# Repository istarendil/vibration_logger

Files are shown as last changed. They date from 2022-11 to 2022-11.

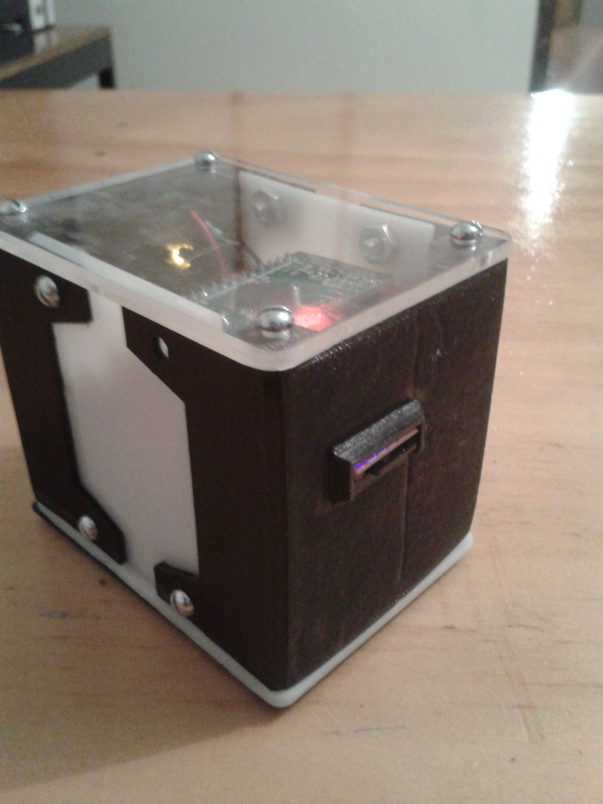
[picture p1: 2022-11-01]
doc/img/2016-10-13 19.51.44.jpg

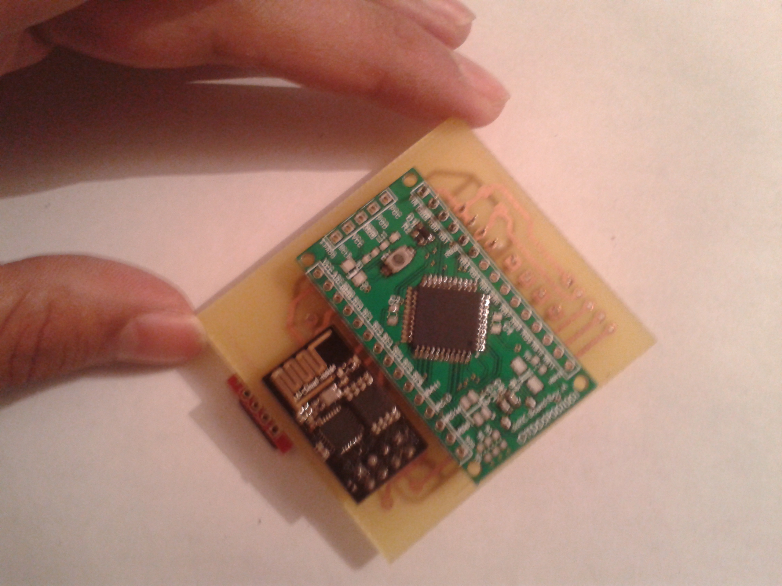
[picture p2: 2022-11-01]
doc/img/2016-09-04 22.14.03.jpg

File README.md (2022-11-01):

# vibration_logger
The main idea of this project is to build a device capable of measuring vibrations in structures such as buildings and transmitting the information obtained to a database that can be accessed remotely through the internet. The objective of having a remote monitoring system is to collect useful data on the state of the buildings for its later analysis.

logger
pcb1

This project was commissioned by the Department of Structural Analysis of the Faculty of Engineering of the Autonomous University of the State of Mexico to the System Dynamics and Control Laboratory. 

pcb2
pcb3

# Tools and materials
- esp8266
- dsPic30f3014
- RTC DS1302

# Software
|name| version|
|----|---|
|MPLAB X| 10 |
|C16 compiler|1.25|
|Matlab| 2016|

# Directories and files
- The firmware/logger directory contains the source code written for the C16 compiler in MPLAB X.
- The firmware/esp8266 folder contains the different versions of the esp8266 firmware.
- The firmware/configuration_files folder contains the necessary files for the operation of the logger and for the connection to the Wi-fi network, as well as a file that shows how the data is stored.
- The pcb folder contains the PCB design files.
- The Excel document at te test folder contains a test performed on the prototype, where data was acquired and the results were graphed.

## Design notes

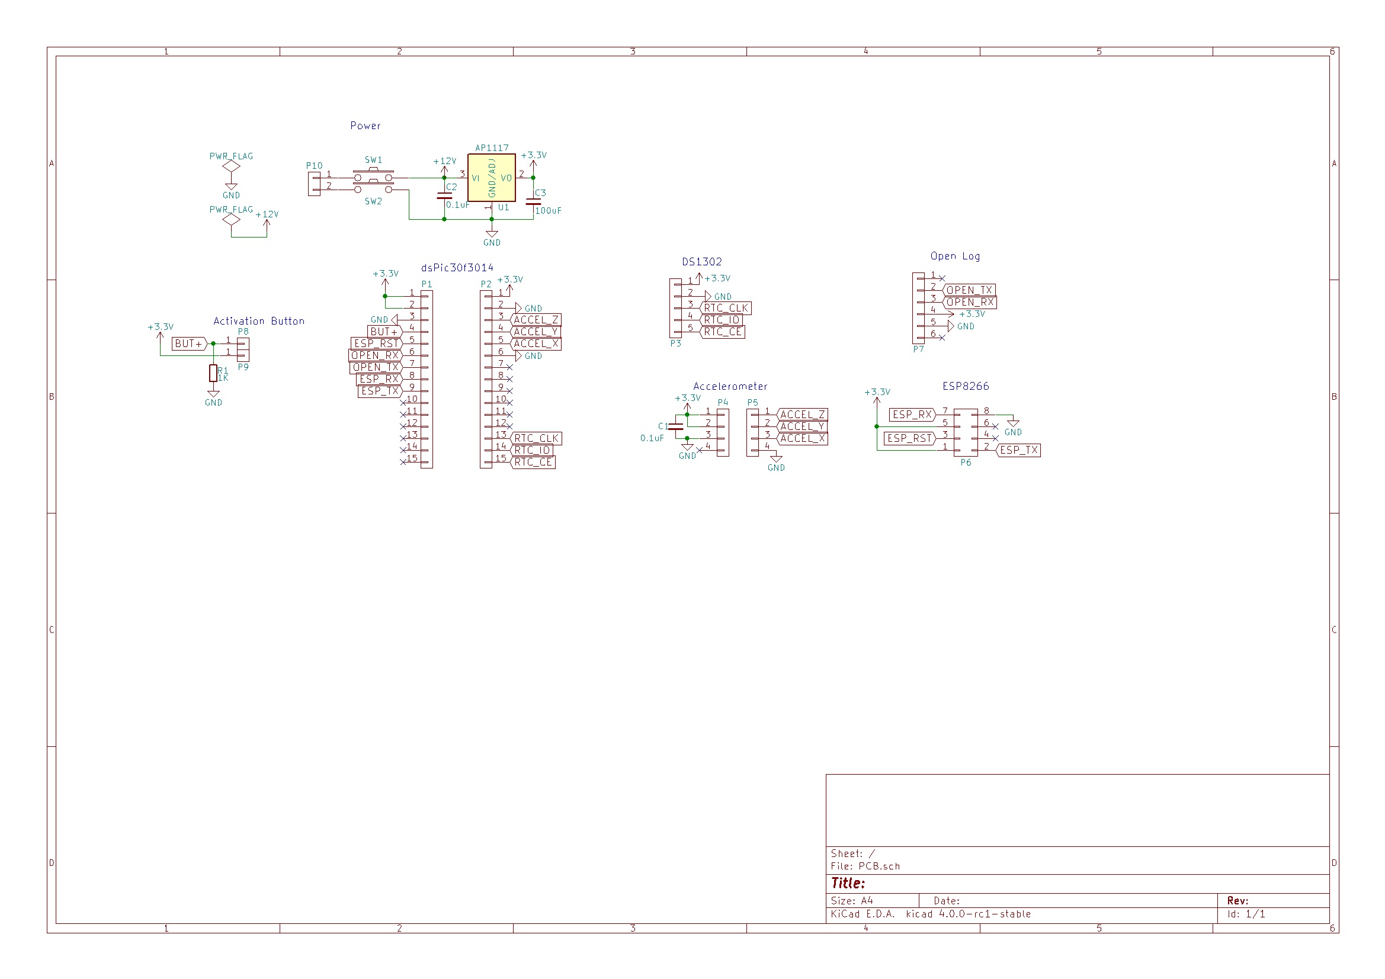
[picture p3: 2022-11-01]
doc/img/Schematic.jpg

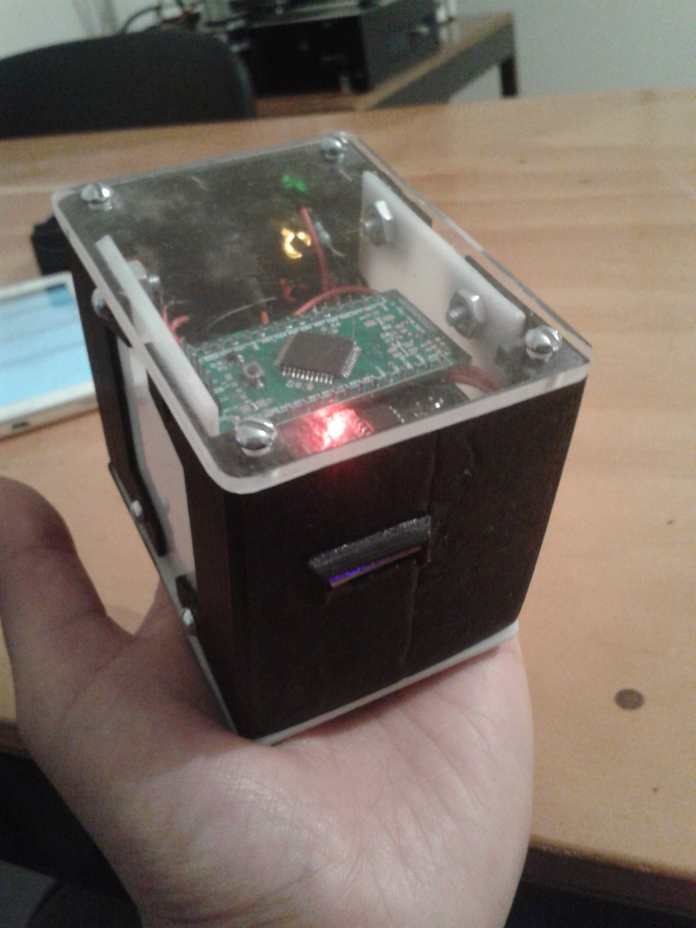
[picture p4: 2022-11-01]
doc/img/2016-10-13 19.52.28.jpg

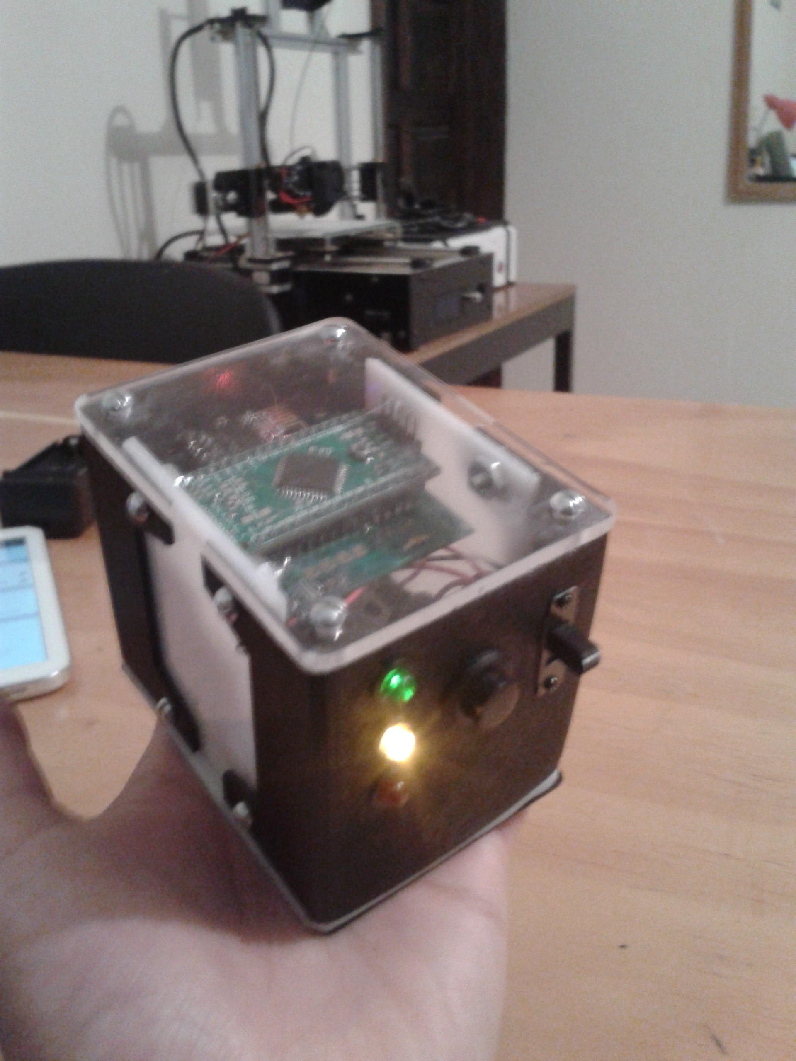
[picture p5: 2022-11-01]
doc/img/2016-10-13 19.52.05.jpg

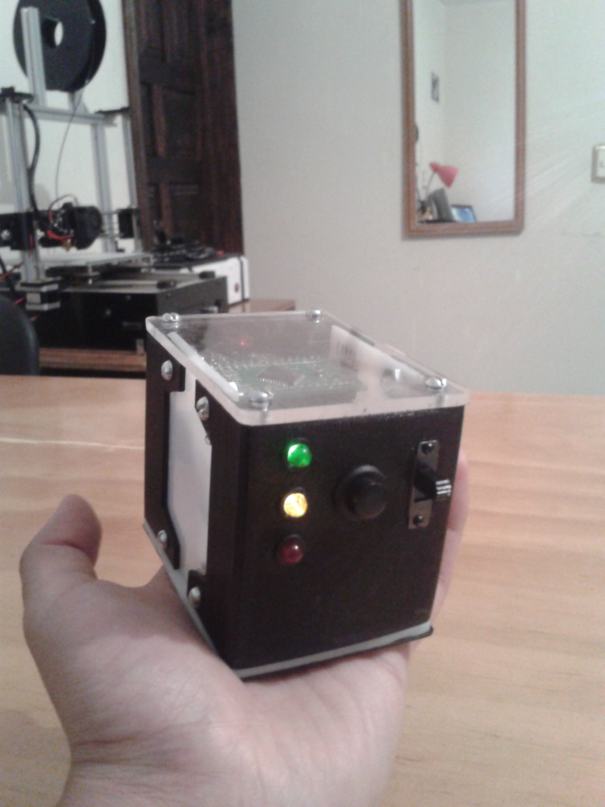
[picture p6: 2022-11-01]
doc/img/2016-10-13 19.56.36.jpg

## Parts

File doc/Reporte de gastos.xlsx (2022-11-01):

Elemento | Cantidad | Provedor | Costo unitario | Costo total
Tarjetas con dsPic | 2 | A-Electronics | $165 | $330
Tarjetas sin dsPic | 1 | A-Electronics | $50 | $50
Baterias Li-Po 3.7v | 2 | A-Electronics | $75 | $150
Cargadores Li-Po 1s | 2 | A-Electronics | $80 | $160
Pilas Li-ion 3.7v | 2 | Electrocomponentes | $90 | $180
Módulos RTC | 2 | A-Electronics | $60 | $120
Cargador de pilas Li-ion | 1 | Mercadolibre | $189+95(envio) | $284
Portapilas doble | 1 | A-Electronics | $35 | $35
Portapilas sencillo | 3 | A-Electronics | $30 | $90
Pilas de boton | 2 | GOMI | $16 | $32
Conectores, botones, resistencias, capacitores, cables, materiales | NA | NA | NA | $214
Inversion total |  |  |  | $1645
Presupuesto original |  |  |  | $2500
Presupuesto restante |  |  |  | $855

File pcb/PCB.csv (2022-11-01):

 |  | ADC-BATT1 | ADC-EXT2 | ADC-EXT3 | ADC-EXT4 | ADC-EXT5 | LED-BATT1 | LED-OK1
Id | Designator | Package | Quantity | Designation | Supplier and ref
1 | C1 | C_1206_HandSoldering | 1 | 100nF
2 | P1P2 | Socket_Strip_Straight_1x15 | 2 | CONN_01X15
3 | P3 | Socket_Strip_Straight_1x05 | 1 | CONN_01X05
4 | P4P5 | Socket_Strip_Straight_1x04 | 2 | CONN_01X04
5 | P7 | Socket_Strip_Straight_1x06 | 1 | CONN_01X06
6 | P8P9
7 | P10LED-ON1" | Socket_Strip_Straight_1x01 | 10 | CONN_01X01
8 | SW1SW2 | Socket_Strip_Straight_1x02 | 2 | SW_PUSH
9 | P6 | Socket_Strip_Straight_2x04 | 1 | CONN_02X04
10 | U1 | sot223 | 1 | AP1117
11 | C2 | c_tant_A | 1 | 1uF
12 | C3 | c_tant_C | 1 | 100uF
13 | R1 | R_0805_HandSoldering | 1 | 1K
14 | R2 | R_0805_HandSoldering | 1 | 12K
15 | R3 | R_0805_HandSoldering | 1 | 22K

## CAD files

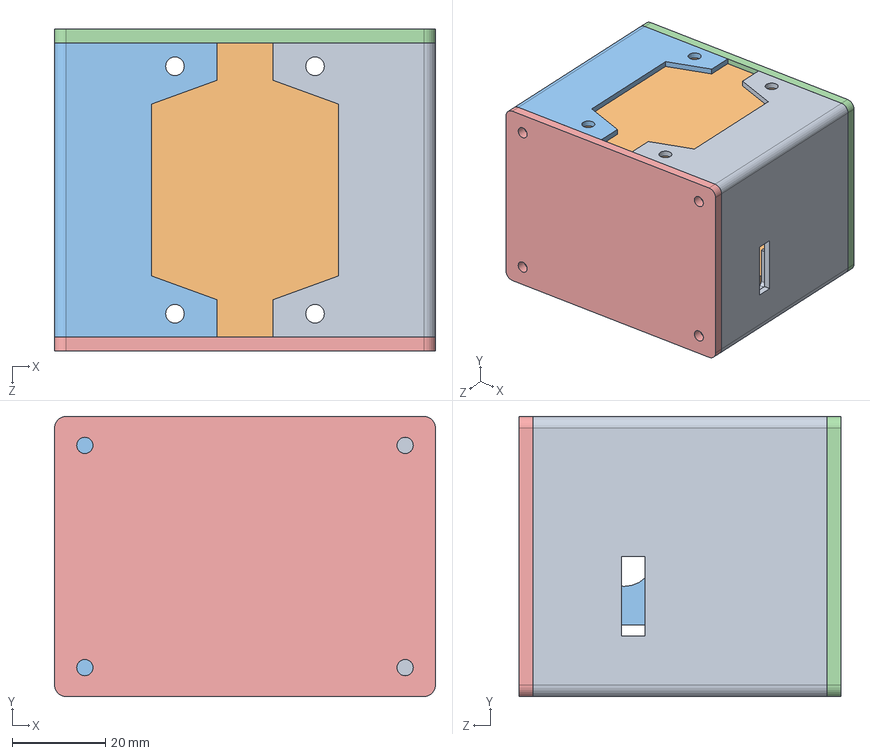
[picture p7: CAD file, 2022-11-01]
cad/case/caja V1.SLDASM
81.6 x 60.0 x 69.0 mm
Tapa frontal
Tapa lateral x 2
Tapa trasera
Tapa superior

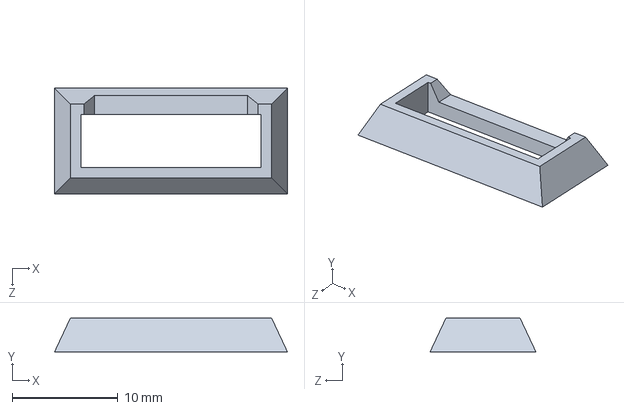
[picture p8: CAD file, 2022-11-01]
cad/case/SD-Card.SLDPRT
22.0 x 3.20 x 10.0 mm

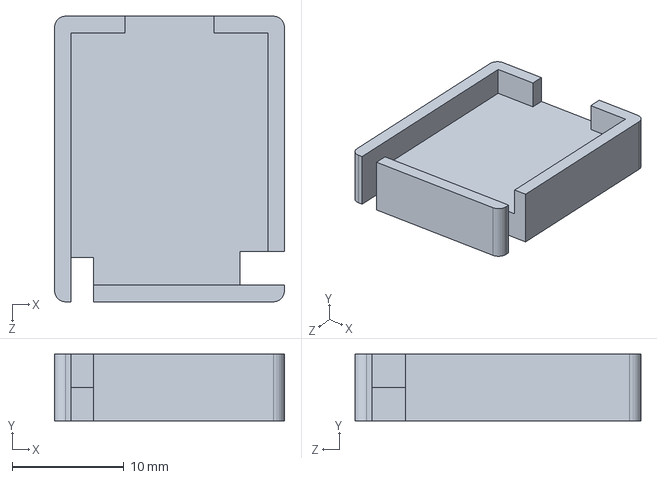
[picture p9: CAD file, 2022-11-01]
cad/charger/Cargador.SLDPRT
20.6 x 6.00 x 25.6 mm

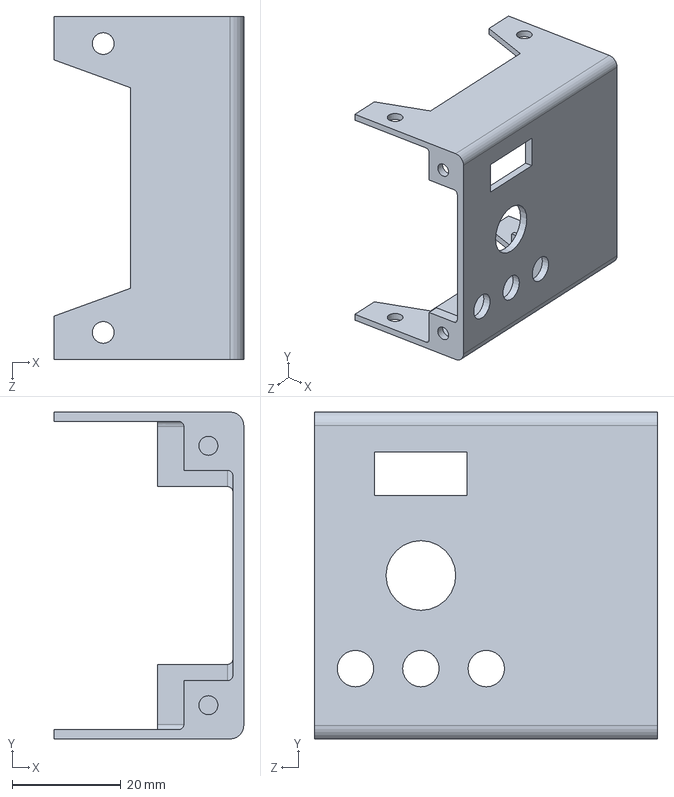
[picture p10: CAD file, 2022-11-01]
cad/case/Tapa trasera.SLDPRT
34.8 x 60.0 x 63.0 mm

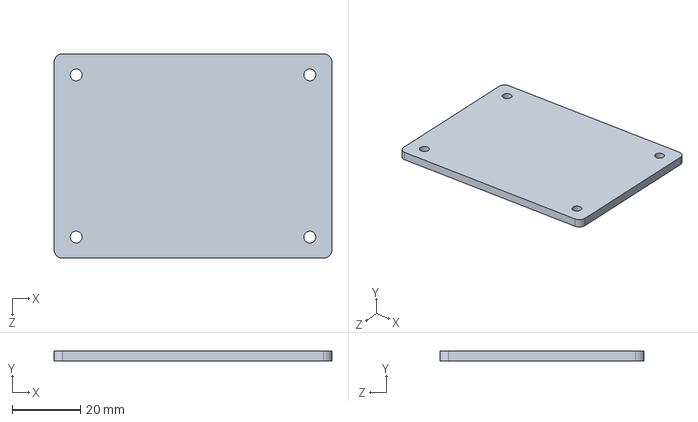
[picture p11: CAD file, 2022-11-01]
cad/case/Tapa superior.SLDPRT
81.6 x 3.00 x 60.0 mm

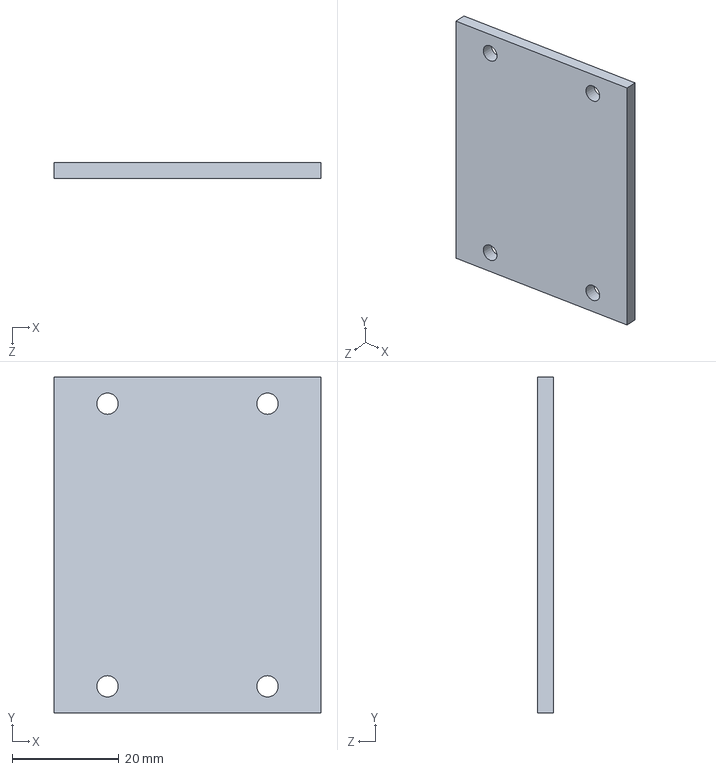
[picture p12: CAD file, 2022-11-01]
cad/case/Tapa lateral.SLDPRT
50.0 x 63.0 x 3.00 mm

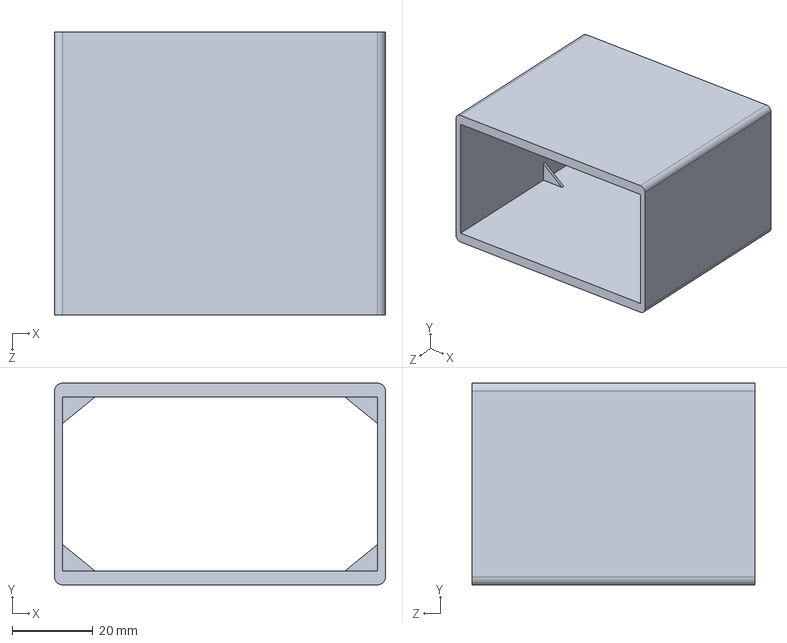
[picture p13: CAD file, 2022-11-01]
cad/case/Pieza1.STEP
82.0 x 50.0 x 70.0 mm

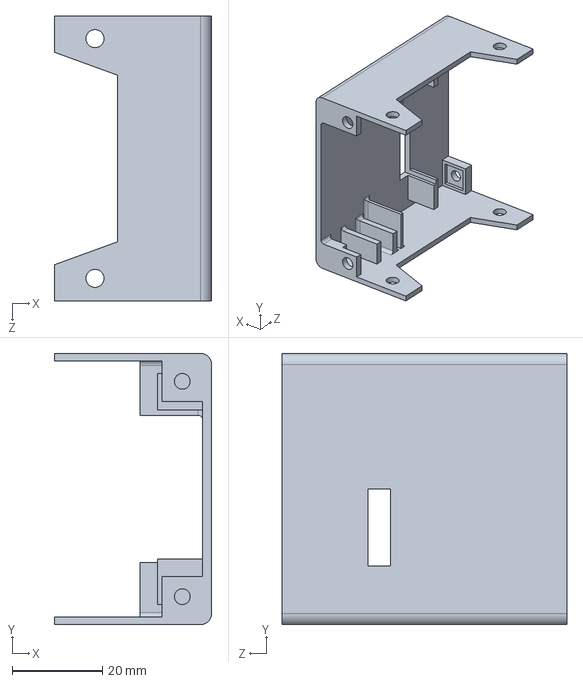
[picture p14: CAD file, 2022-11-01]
cad/case/Tapa frontal.SLDPRT
34.8 x 60.0 x 63.0 mm

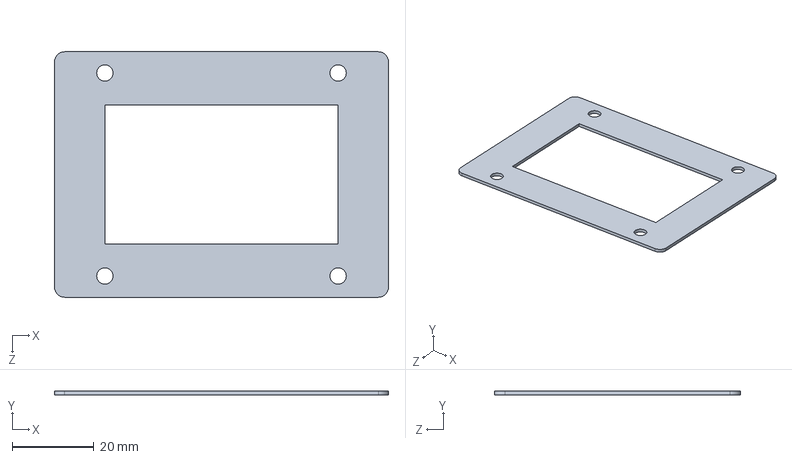
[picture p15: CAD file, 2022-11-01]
cad/case/Tapa inferior.SLDPRT
81.6 x 1.00 x 60.0 mm

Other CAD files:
cad/case/SD-Card.STL
cad/case/Tapa frontal.STL
cad/case/Tapa inferior.SLDDRW
cad/case/Tapa inferior.STL
cad/case/Tapa lateral.SLDDRW
cad/case/Tapa superior.SLDDRW
cad/case/Tapa trasera.STL
cad/charger/Cargador.STL

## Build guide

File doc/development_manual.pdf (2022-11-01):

# Registrador de vibraciones v1.0

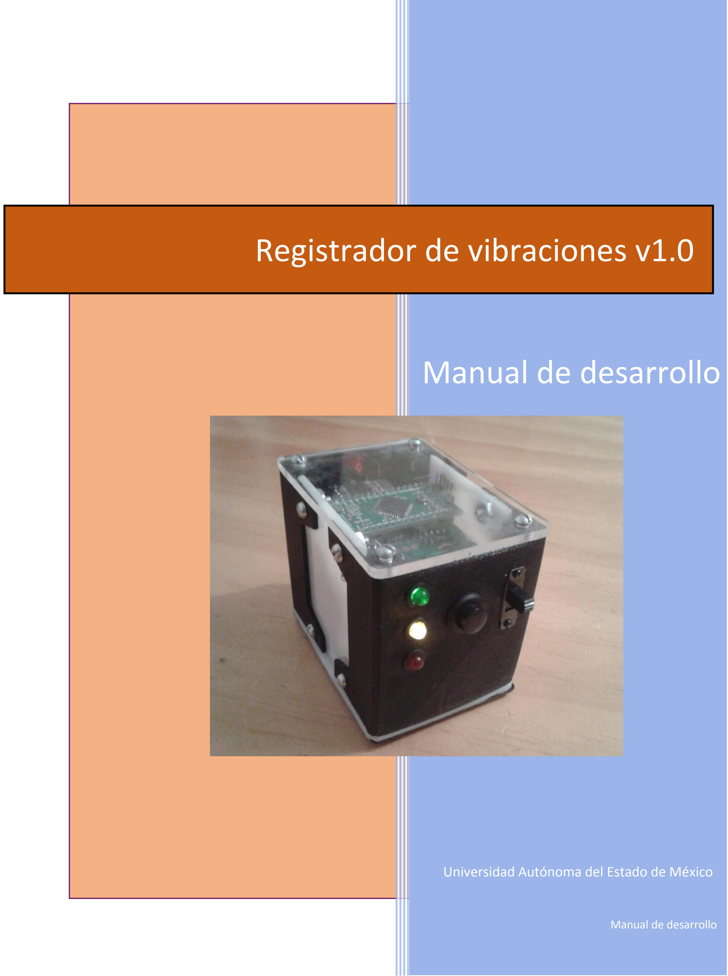
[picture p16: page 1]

# Manual de desarrollo

Universidad Autónoma del Estado de México

Manual de desarrollo

### Registrador de vibraciones v1.0

## Contenido

### 1. Programación del módulo Wi-Fi

El módulo ESP8266 es el elemento encargado de dar conectividad web al dispositivo. Originalmente viene precargado con un firmware que lo hace funcionar mediante comandos AT lo cual resulta conveniente si se desea configurara manualmente, pero dificulta su uso si se desea conectarlo a un microcontrolador.

Para facilitar el desarrollo de este proyecto el firmware del módulo ESP fue reescrito empleando el IDE de Arduino, esto permitió conectarlo a los servidores de la empresa Adafruit para crear un dispositivo de internet de las cosas capaz de ser activado en forma remota a través de una interfaz web.

1.1Requerimientos previos
Materiales empleados
- Esp8266-01
- Interfaz USB-serial FTDI232
- Arduino IDE 1.6.9

Instalación del Plug-in ESP8266 en el Arduino IDE

Instalar este plug-in en el IDE de Arduino permitirá programar el módulo wi-fi como una tarjeta arduino. A continuación se muestran los pasos para lograr esta tarea.

a) Abrir el IDE de arduino e ir a Archivo/Preferencias. En el recuadro de Gestor de URL´s adicionales de Tarjetas escribir la siguiente liga:

http://arduino.esp8266.com/package_esp8266com_index.json

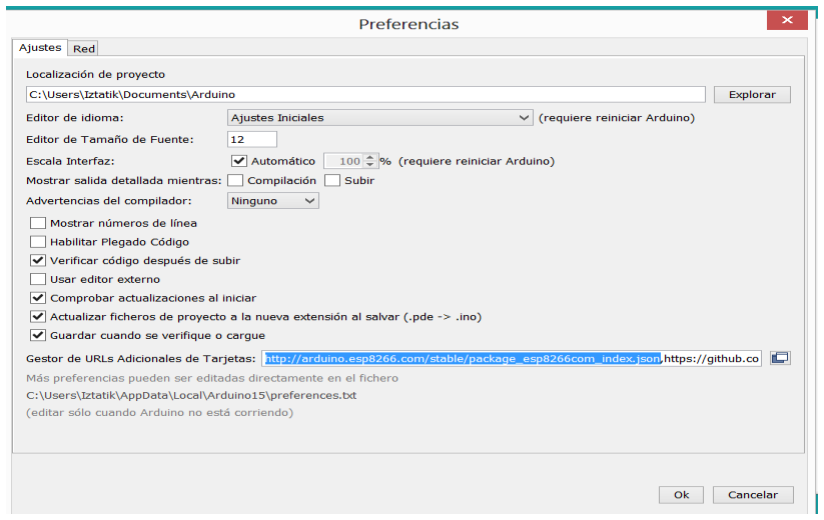
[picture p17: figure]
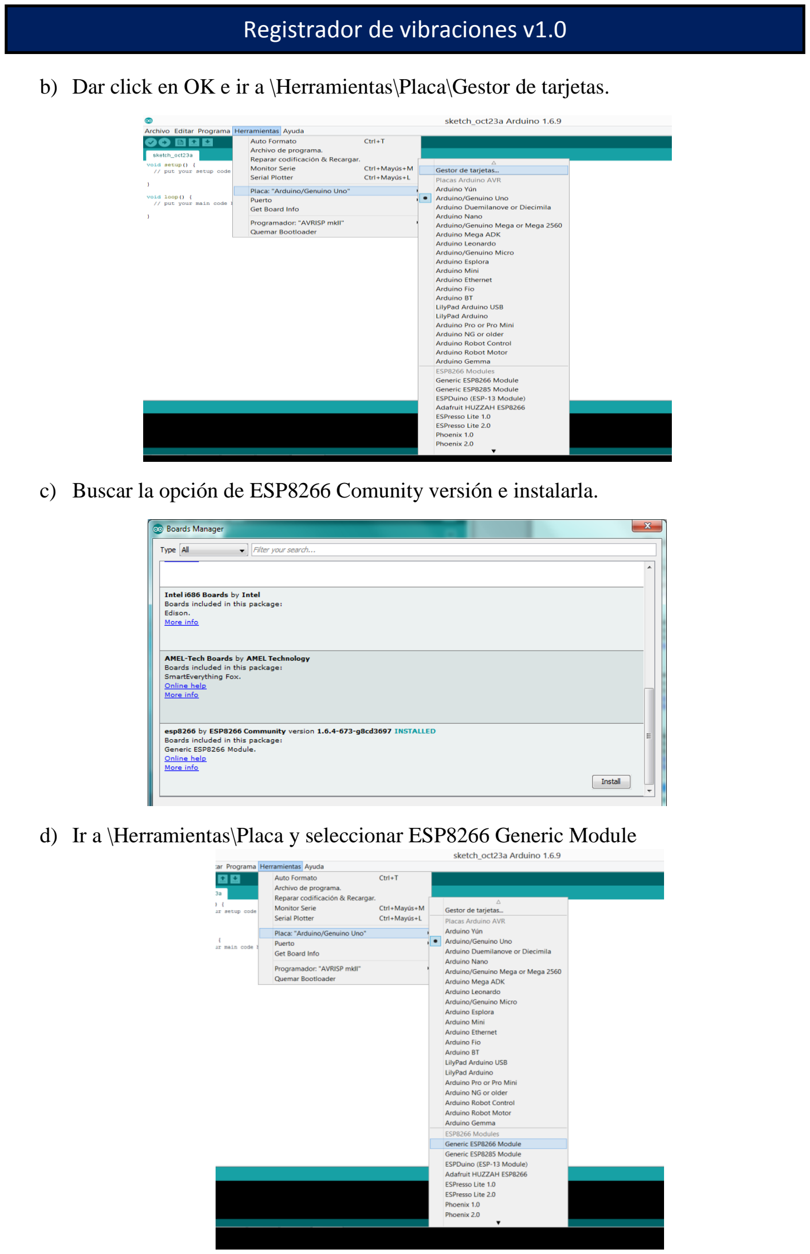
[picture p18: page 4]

b) Dar click en OK e ir a \Herramientas\Placa\Gestor de tarjetas.
c) Buscar la opción de ESP8266 Comunity versión e instalarla.
d) Ir a \Herramientas\Placa y seleccionar ESP8266 Generic Module e) Conectar la interfaz FTDI al módulo Wi-fi de la siguiente manera:

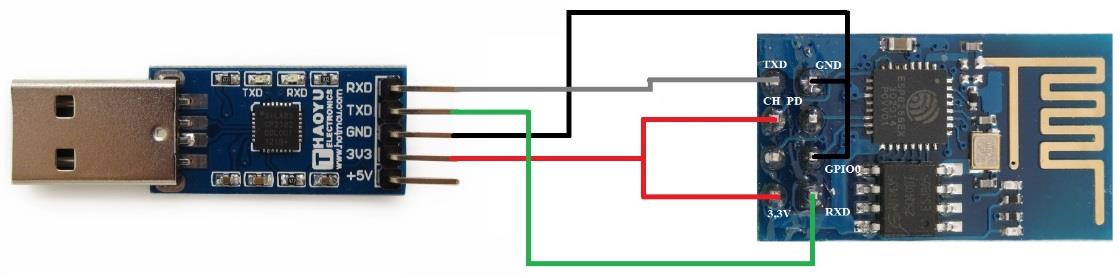
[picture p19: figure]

Instalación de la librería MQTT de Adafruit en el Arduino IDE

Esta librería permite la conexión del módulo Wi-fi a los servidores de la empresa Adafruit.

1) Diríjase al menú de Programa/Incluir Librería/ Gestor de Librerias

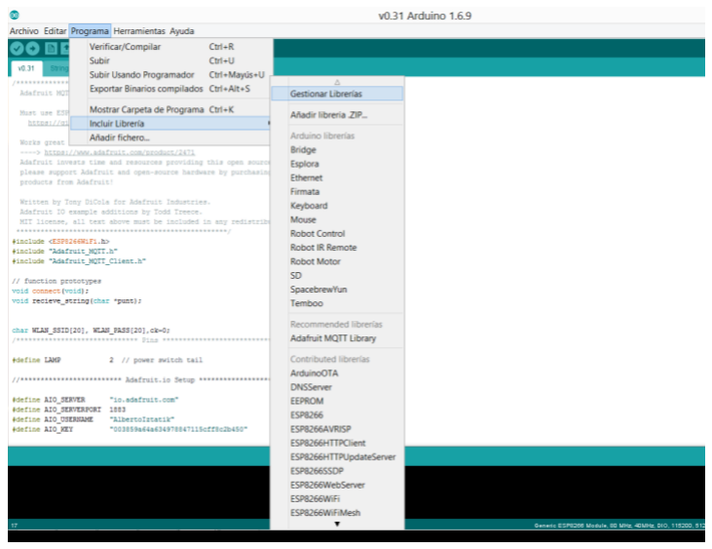
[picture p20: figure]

2) En el filtro de búsqueda escriba Adafruit. Busque, seleccione y de click en instalar a la opción de Adafruit MQTT Library.

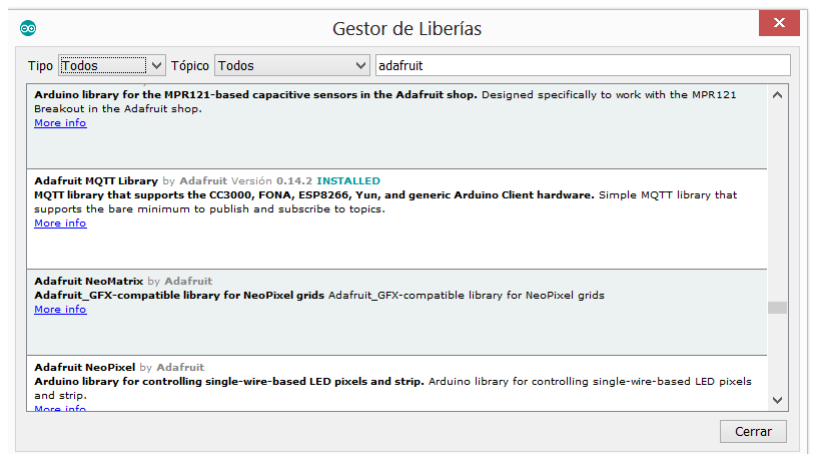
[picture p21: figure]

### 1.2 Creación de la interfaz web

Para la creación de la interfaz web es necesario tener un perfil o crear uno en la página oficial de Adafruit: https://accounts.adafruit.com/users/sign_in

Una vez creada la cuenta deben seguirse los siguientes pasos:

1) Ingresar a la página https://io.adafruit.com/ e iniciar sesión. Ir a la sección MyFeeds y crear un Feed con el nombre “lamp”. Se ha escogido este nombre con la finalidad de coincidir con el nombre planteado en el ejemplo base y la programación explicada en la sección 1.3.

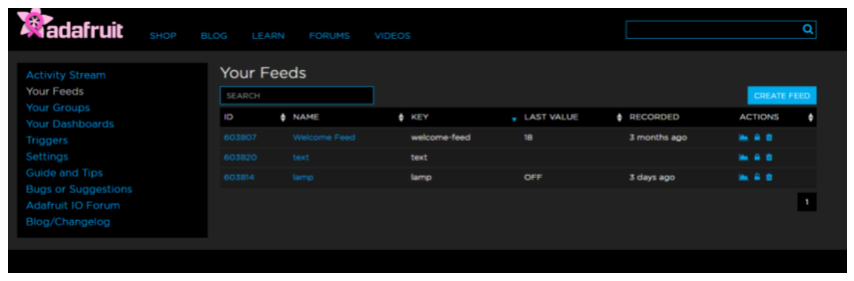
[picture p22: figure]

2) Ir a la sección My dashboarads y seleccionar Create Dashboard.

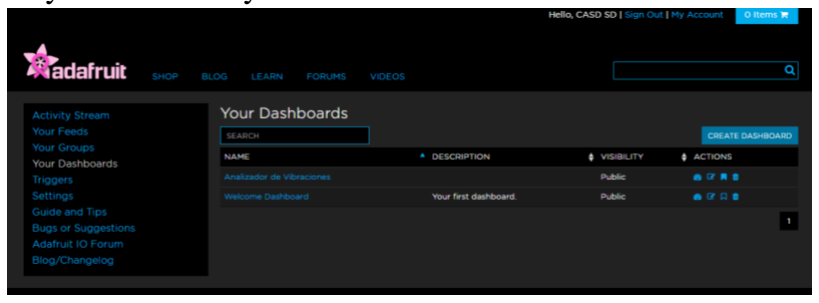
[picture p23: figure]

3) Seleccionar las opciones edit dashboard y créate block. Crear un elemento tipo botón y un elemento tipo cuadro de texto, ambos bajo el Group/Feed de “lamp”. Debe cuidarse que el campo de button on text sea llenado con la palabra “ON” y el button off text sea llenado con la palabra “OFF”

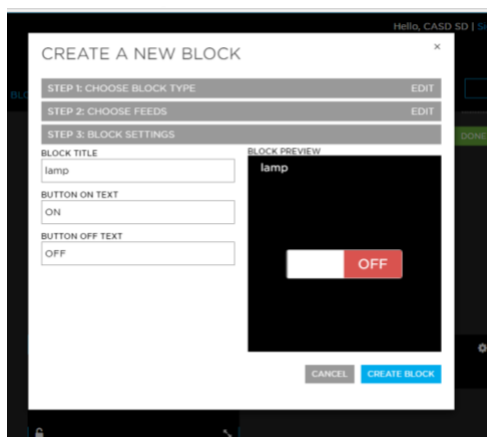
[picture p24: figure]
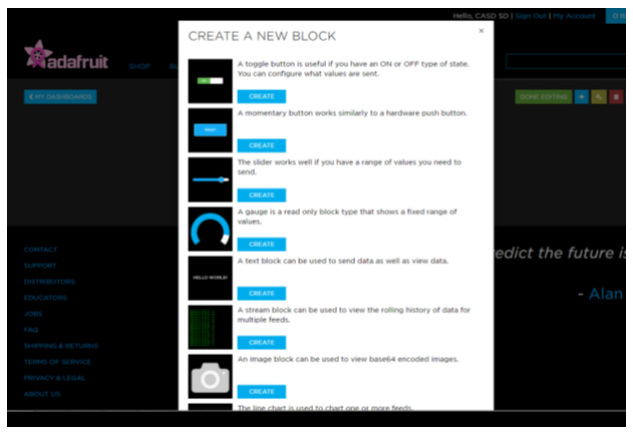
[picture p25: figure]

4) El resultado será una interfaz como la que se muestra a continuación:

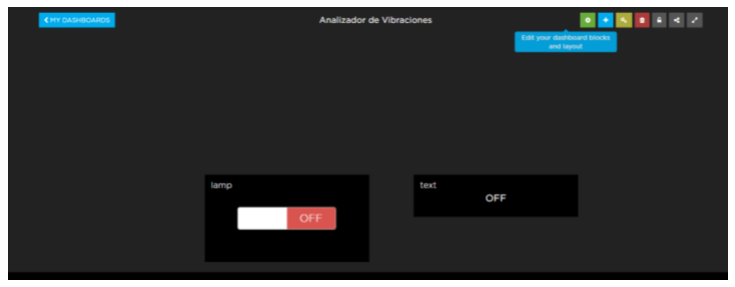
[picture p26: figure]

Para mayor información seguir la documentación disponible en la siguiente liga: https://learn.adafruit.com/adafruit-io-basics-feeds/overview

1.3Programación del módulo

Para la programación del módulo se tomó como base la idea fundamental del envío de una señal para el inicio o término de la grabación de datos del dispositivo. Para ello se partió de un ejemplo de código de la empresa Adafruit, el cual enciende y apaga una lámpara de forma remota a través de una interfaz web. El ejemplo puede ser descargado de la siguiente liga:

https://github.com/adafruit/adafruit-io-basics/tree/master/esp8266/digital_out

Teniendo este ejemplo como base se hicieron las siguientes modificaciones:

1) El ejemplo original contempla que se programe el nombre y clave de la red wlan de forma anticipada, no obstante esto se traduce en la necesidad de reprogramar el módulo cada vez que se quiera cambiar de red. Para evitar esto, se declararon estos valores como variables las cuales son definidas mediante una lectura serial cada vez que se enciende el módulo.

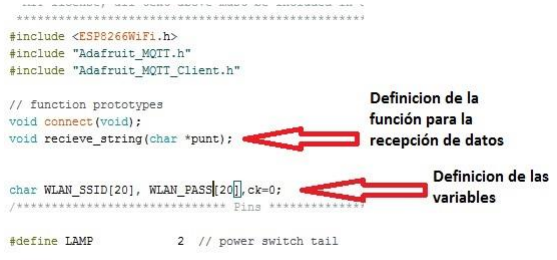
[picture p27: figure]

2) Se creó una función encargada de recibir los datos de las variables WLAN_SSID y WLAN_PASS cada vez que se enciende el módulo. Debe notarse que el código fuente de esta función se encuentra en una pestaña aparte de la función principal.

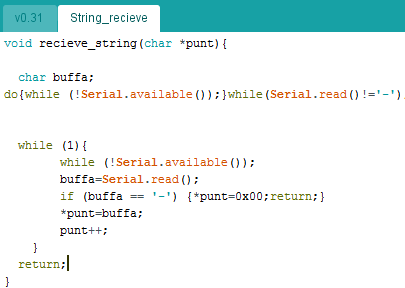
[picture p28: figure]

3) En la sección de definiciones se introdujeron el nombre de usuario y las claves AIO generadas al crear la interfaz web.

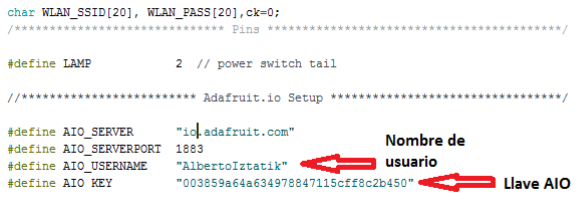
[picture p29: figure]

4) La función void setup fue modificada para iniciar la conexión wifi hasta asegurar la recepción vía serial y la definición de las variables del nombre y clave de la red wlan. También se modificó la velocidad de transmisión serial a 57600 baudios. En la función Serial.begin.

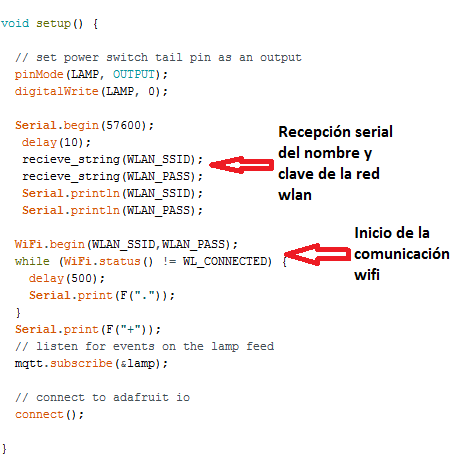
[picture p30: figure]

5) Se modificó la función void loop ara que al recibir la señal de encendido “ON” de la interfaz web, el módulo ESP envié de forma serial la letra “s” indicando el inicio de una nueva grabación de datos. De igual manera, al recibir una señal “OFF” el módulo ESP enviará de forma serial la letra “e” indicando la finalización de la grabación de datos. El DSC conectado al módulo ESP recibirá estos datos por su puerto serial y ejecutará las operaciones mencionadas.

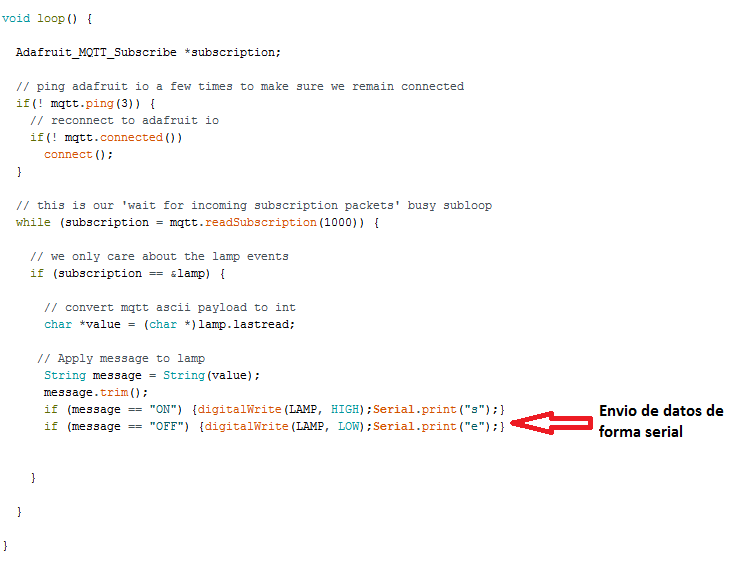
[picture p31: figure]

6) A lo largo de todo el código se eliminaron las impresiones seriales por el puerto serie que estaban definidas a excepción de las que muestra que el estado de conexión esta en proceso (.) y la que muestra una conexión exitosa (+).

Para mayor información seguir la documentación disponible en la siguiente liga: https://learn.adafruit.com/home-automation-in-the-cloud-with-the-esp8266-and-adafruit-io/introduction (https://learn.adafruit.com/home-automation-in-the-cloud-with-the-esp8266-and-adafruit-io/introduction)

### 2. Configuración del lector de tarjetas SD

EL lector de tarjetas SD Open Log se configura mediante tres archivos de texto. A

continuación se detalla la función de los mismos:

1) Archivo COUNT.- Lleva un conteo de los archivos de grabación generados,

permitiendo que el DSC conozca la cantidad de archivos generados hasta el momento

y pueda generar el archivo siguiente en la lista.

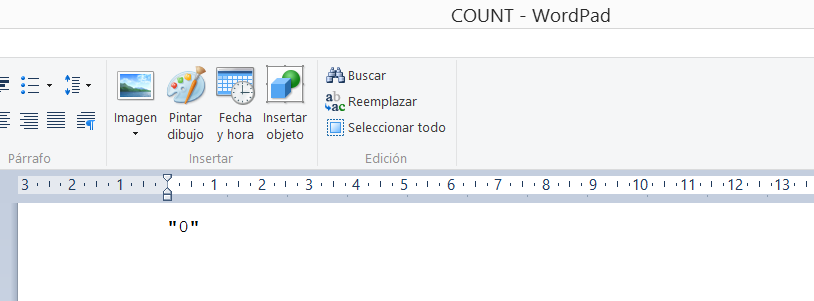
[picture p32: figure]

2) Archivo WLAN.- contiene los datos de la red de área local a la cual se conectará el

dispositivo, el DSC leerá este archivo para obtener esa información y posteriormente

enviarla al módulo ESP para que este realice la conexión.

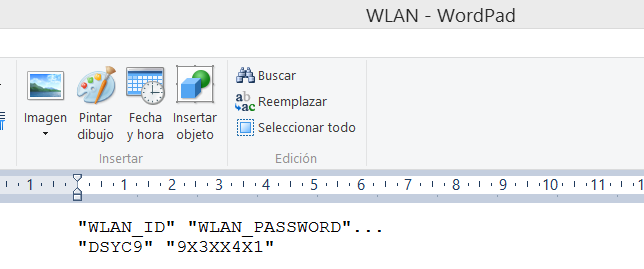
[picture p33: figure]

3) Archivo CONFIG.- Contiene los parámetros de configuración básica para la

comunicación serial de la tarjeta. Estos son en orden:

- Baudrate.- Velocidad de la conexión. 57600 para esta aplicación.
- Escape.- Valor en ASCII del carácter que permite poner al Open Log en modo

comando. Ctrl+z para esta aplicación.

- Esc#.- número de veces que debe leerse el carácter de escape para poner al Open

Log en modo comando. 3 para esta aplicación.

- Mode.- Modo con el que inicia el Open log al encenderse en cada ocasión. Modo

comando para esta aplicación (valor 0).

- Verb.- Responde con un carácter cada que se produce un error al leerse un

comando no reconocido. Apagado para esta aplicación (valor 0).

- Echo.- Responde con un carácter cada que se lee un dato por el puerto serial.

Apagado para esta aplicación (valor 0).

- Ignore RX.- Ignora la línea serial de RX por un periodo cada que se enciende el

Open Log. Apagado para esta aplicación (valor 0).

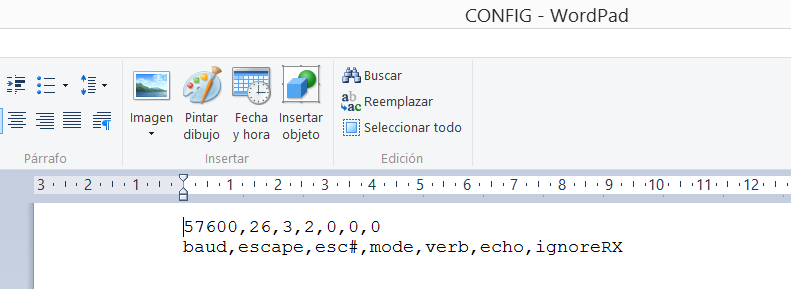
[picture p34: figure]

### 3. Programación del DSC

Herramientas empleadas:

- MPLABX IDE V3.10
- C16 Compliler V1.25
- Programador Pickit3
- dsPic30f3014

3.1Funciones del DSC

El DSC (controlador digital de señales) es el elemento de control principal del dispositivo. Como tal, es el encargado de interactuar con los otros elementos y gestionar sus tareas. A continuación se enumeran las funciones del DSC respecto a todos los elementos:

Lector de tarjetas SD Open Log:

- Creación y finalización de un nuevo archivo de grabación.- Al presionar el botón físico o virtual (interfaz web) el dispositivo leerá el contenido del fichero COUNT de la SD, incrementara en un valor este conteo, rescribirá dicho fichero con el valor incrementado y creará un nuevo fichero con el nombre del valor del conteo incrementado donde grabara los datos obtenidos del acelerómetro.
- Lectura del archivo de configuración de la red wlan.- Cada vez que se enciende el dispositivo, el DSC leerá vía serial los datos necesarios para la conexión a una red de área local del fichero WLAN en la tarjeta SD, posteriormente enviará estos datos al módulo wifi para que este pueda la conexión.

Módulo wifi ESP8266

- Envió de los datos de la red wlan.- El DSC lee estos datos del fichero WLAN de la tarjeta SD y posteriormente los envía vía serial al módulo ESP para que este entable la conexión.
- Recepción de los datos de activación.- Cada vez que se presiona el botón de la interfaz web, el DSC recibe vía serial las instrucciones para la creación o finalización de un archivo de grabación.

Reloj en tiempo Real

- Lectura del RTC.- El DSC lee el valor del reloj en tiempo real cada que se inicia o finaliza un archivo de grabación para escribir la hora en la que este fue iniciado y terminado.

Botón del dispositivo.- El DSC detectará que se ha presionado dicho botón e iniciará o detendrá la grabación de datos.

Gestión de energía de la batería.- El DSC determinará el nivel de carga de las pilas y encenderá el led rojo cuando estas estén totalmente descargadas.

3.2Mapa de conexión con otros elementos del dispositivo

El DSC y en general todos los elementos del dispositivo se encuentran conectados entre sí como muestra el siguiente diagrama esquemático:

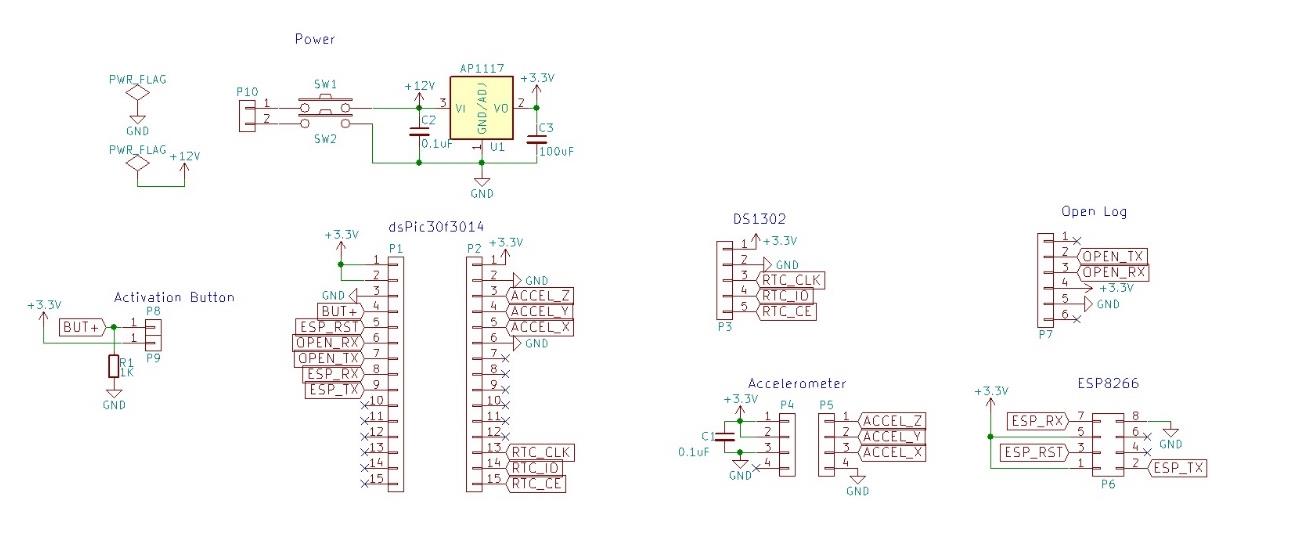
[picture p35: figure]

3.3Estructura del código fuente

El código fuente ha sido organizado en distintos ficheros para hacerlo lo más modular posible, dichos ficheros contienen un conjunto de funciones que al ser invocadas realizan funciones específicas del sistema. A continuación se detalla cada uno de estos ficheros y las funciones que contiene:

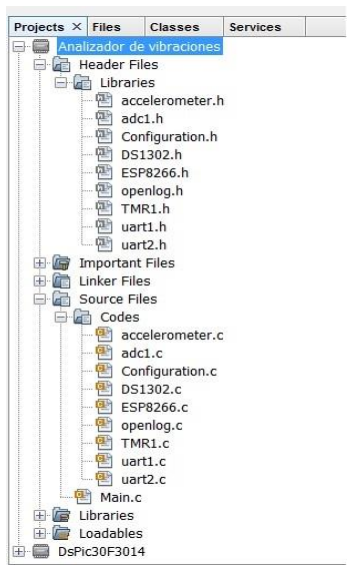
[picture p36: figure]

Archivos de cabecera:

a) accelerometer.h.- definición de variables y funciones del archivo acelerometer.c.
b) adc.h.- definición de variables y funciones del archivo adc.c.
c) Configuration.h.- definición de la frecuencia de reloj del sistema, inclusión de las librerías a emplear.
d) DS1302.h.- definición de variables y funciones del archivo DS1302.c
e) ESP8266.h.- definición de variables y funciones del archivo ESP8266.c.
f) openlog.h.- definición de variables y funciones del archivo openlog.c
g) TMR1.h.- Definición de la frecuencia de las interrupciones para las lecturas del ADC.
h) uart1.h.- Frecuencia y funciones para la comunicación serie con el Open Log
i) uart2.h.- Frecuencia y funciones para la comunicación serie con el ESP.

Archivos de código fuente:

a) accelerometer.c:
- ACCEL_get ().- Regresa la lectura de cualquier eje del acelerómetro convertida a un valor de voltaje.
b) adc.c:
- ADC1_initialize().- configura el ADC para su funcionamiento
- ADC1_getdata ().- realiza “manuelamente” el proceso de muestreo y conversión de un dato del ADC.
- BATT_get ().-Regresa la lectura del voltaje de la batería convertido a un valor de voltaje.
c) Configuration.c.- Contiene la definición de los fuses del DSC.
- SYSTEM_initialize ().- invoca todas las funciones de inicialización de cada función y gestiona el tiempo de retardo para que se ejecuten.
d) DS1302.h:
- DS1302_initialize ().- Inicializa el DS1302.
- DS1302_write ().- Hace una lectura en los registros del DS1302.
- DS1302_read ().- Realiza una lectura de los registros del DS1302.

- DS1302_bcd2bin ().- Convierte un dato de BCD a binario.
- DS1302_rgtclean ().- Determina el registro del RTC con el que se trabajará.
e) ESP8266.c:
- initilize_ESP8266 ().- Inicializa el ESP poniendo su pin de reset a 0.
- wlan_ESP8266 ().- Envía el ESP de forma serial los datos necesarios para la conexión a la red wlan.
f) openlog.c:
- OPENLOG_initilize ().- Lee los archivos WLAN y COUNT de la SD e invoca la función wlan_ESP8266 ().
- OPENLOG_get_string ().- Recibe una cadena de caracteres del puerto serial.
- OPENLOG_parser ().- Función que ejecuta un algoritmo de búsqueda en el string recibido para extraer la información útil.
- OPENLOG_completewrite ().- Escribe en una sola invocación las lecturas obtenidas del acelerómetro.
- OPENLOG_comandmode ().- Hace que el Open Log entre en modo comando.
- OPENLOG_newfile ().- crea un nuevo fichero de grabación en el Open Log.
- OPENLOG_printtime ().- Obtiene la hora del RTC y la imprime en un archivo en uso del Open Log.
g) TMR1.c:
- TMR1_initialize ().- Configura el timer 1 para realizar interrupciones cierto periodo.
h) uart1.c:
- UART1_initialize ().- Configura la comunicación serial.
- UART1_send_string ().- Envía una cadena de caracteres por el puerto.
i) uart2.c:
- UART2_initialize ().- Configura la comunicación serial.
- UART2_send_string ().- Envía una cadena de caracteres por el puerto.
- UART2_get_string ().- Recibe una cadena de caracteres por el puerto serial.
- _U2RXInterrupt ().- Rutina de interrupción que se genera al recibir un dato por el puerto.

Función principal main

La función main ejecuta el siguiente algoritmo:

1. Invoca la función SYSTEM_initialize () para inicializar todos los elementos.
2. Define las variables de la función.
3. Define el pin del botón como entrada y los pines de los leds como salidas.
4. Enciende el led verde indicando que el dispositivo está listo para iniciar una grabación, apaga el led rojo de la batería.
5. En el bucle infinito espera a que se produzca algún evento que inicie la grabación (presionar el botn o recepción serial).
6. Si se inicia la grabación se espera un tiempo para evitar rebotes del botón, se enciende el led amarillo y se genera un nuevo archivo.
7. Repetidamente se leen los datos de los ejes del acelerómetro y la batería, los primeros se imprimen en el archivo creado y el segundo se compara con un valor umbral que prende o apaga el led rojo.
8. Si se presiona de nuevo algún botón se apaga el led amarillo y se regresa al estado descrito en el inciso 5.

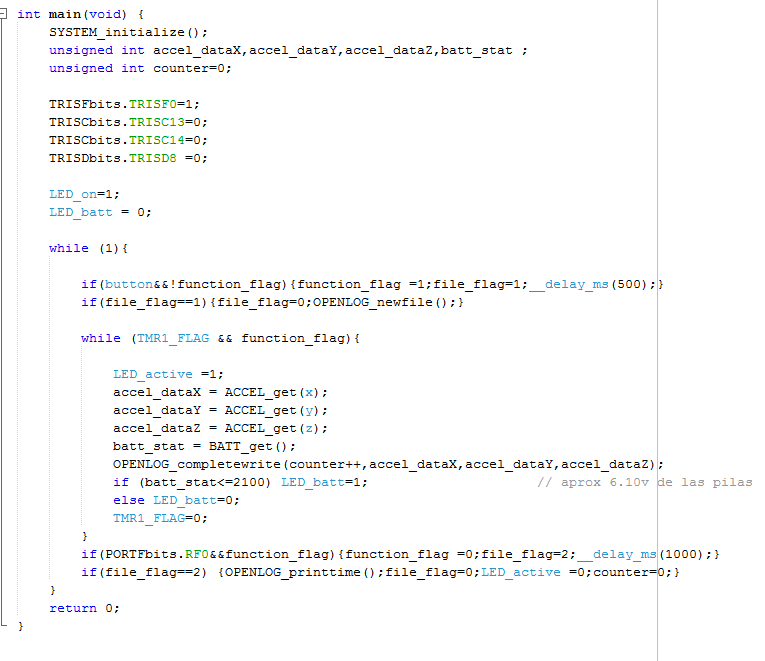
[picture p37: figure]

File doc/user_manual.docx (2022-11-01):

Manual de usuario

Universidad Autónoma del Estado de México

Manual de usuario

Registrador de vibraciones v1.0

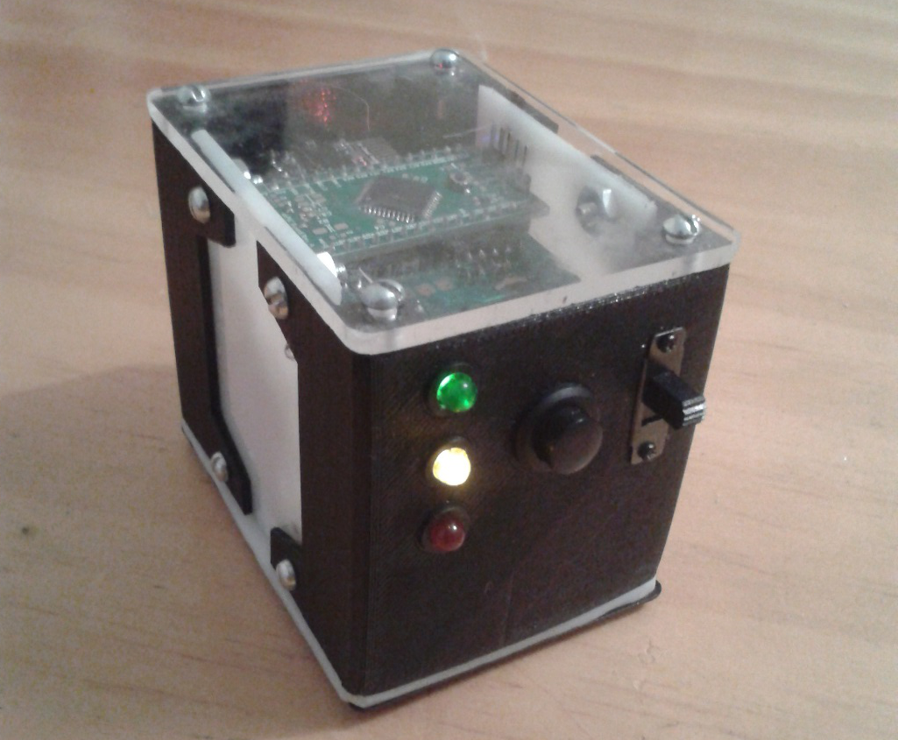
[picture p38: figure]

# 1. Partes del dispositivo

El dispositivo consta de las siguientes partes en la tapa frontal:

1. Interruptor de encendido y apagado.- Enciende el dispositivo al ponerse en una posición alta.
2. Botón de grabación de datos.- Al pulsarse inicia una nueva grabación de datos o detiene alguna en proceso.
3. Leds indicadores de estado
- Led verde.- Indica cuando el dispositivo está listo para comenzar la grabación de datos.
- Led amarillo.- Indica que la grabación de datos está en proceso.
- Led rojo.- Al encenderse totalmente (sin parpadeos), indica una carga baja de las pilas.

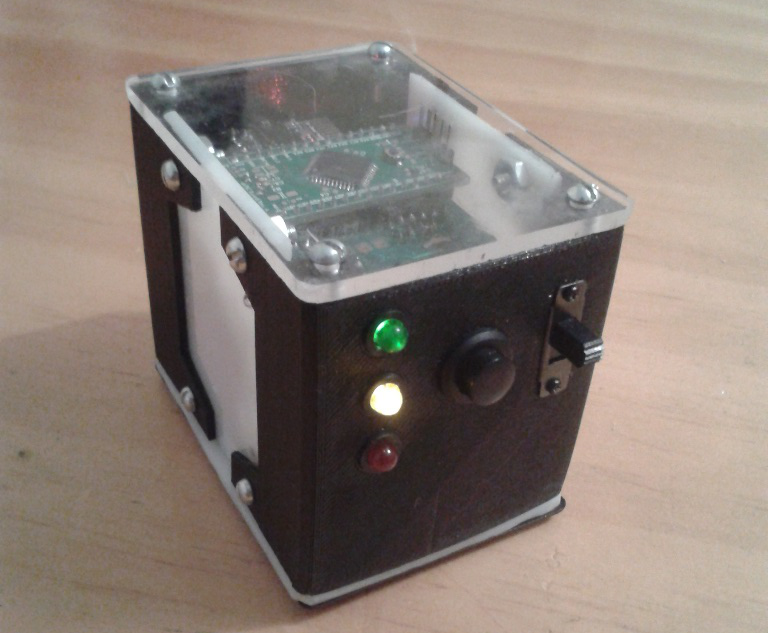
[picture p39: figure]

Figura 1: Vista frontal

El dispositivo consta de las siguientes partes en la tapa trasera:

1. Ranura de inserción para memoria micro SD.- Apartado donde se inserta la tarjeta SD.

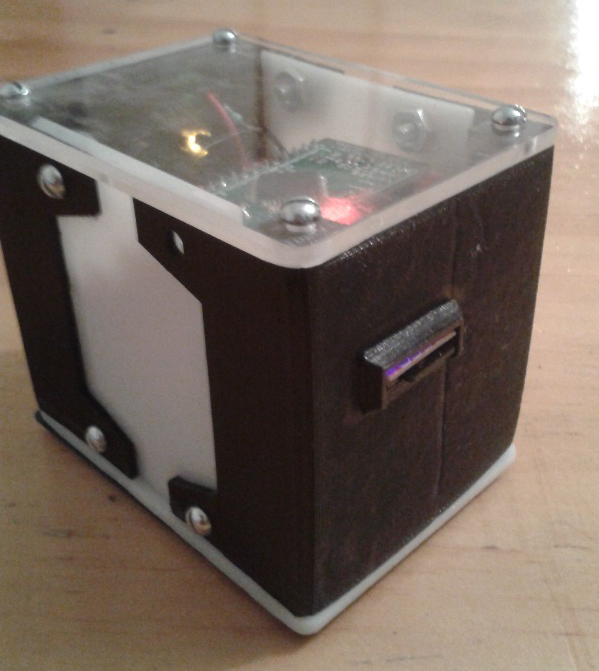
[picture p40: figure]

Figura 2: Vista trasera

# 2. Configuración y uso

A continuación se enumeran los pasos para utilizar el dispositivo:

1) Borre todos los documentos dentro de la tarjeta micro SD o de preferencia fórmatela a su valores de fábrica.
2) Copie los archivos CONFIG, COUNT y WLAN (carpeta Open_Log del CD) a la memoria micro SD.
3) Asegúrese que los archivos estén configurados de la siguiente manera:

El archivo COUNT lleva un conteo de los archivos de grabación generados, asegúrese que su valor inicial sea cero y este entrecomillado como muestra la siguiente imagen, de lo contrario se producirá un error.


Figura 3: Archivo COUNT

El archivo WLAN contiene los datos de la red de área local a la cual se conectará el dispositivo, introduzca estos datos de la forma en que los marcan los tirulos en el archivo, en el primer entrecomillado el nombre de la red y en el segundo entrecomillado la contraseña. De ninguna manera borre o altere los títulos en el primer renglón.


Figura 4: Archivo WLAN

El archivo CONFIG no debe ser modifica bajo ninguna circunstancia y debe asegurarse que coincida con los valores mostrados en la siguiente imagen.

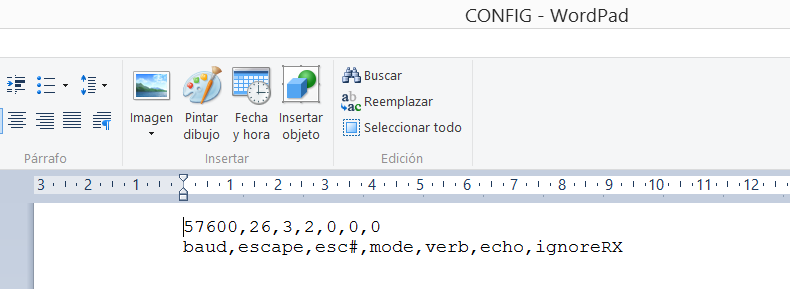
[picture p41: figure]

Figura 5: Archivo CONFIG

4) Inserte la tarjeta en la ranura y encienda el dispositivo accionando el interruptor en la tapa frontal
5) Observe la tapa superior (transparente) aproximadamente 5 segundos hasta que se produzca un destello azul proveniente del módulo wi-fi. Acto seguido, espere a que el led verde en la tapa frontal se encienda, esto indica que el dispositivo está listo para realizar una lectura.
6) Para realizar una lectura, presione y suelte rápidamente el botón ubicado en la tapa frontal. El led amarillo se encenderá indicando que la grabación de datos está en proceso. Repita este paso tantas veces como lecturas necesite.
7) Para retirar la tarjeta SD, siempre detenga cualquier grabación y apague con anterioridad el dispositivo. Retirar la tarjeta mientras se ejecuta un grabación o mientras el dispositivo está encendido puede corromper los datos de la misma, llevando a la necesidad de repetir los pasos 1 a 3.

No es necesario formatear la tarjeta y modificar los archivos de configuración cada ocasión que se use el dispositivo, para usos posteriores al primero simplemente trabaje desde el paso 4. Se recomienda revisar el estado de los archivos de configuración periódicamente para evitar fallos. Asegúrese de que los archivos no contengan espacios o saltos de línea al final de los datos requeridos.

Advertencia: Si después de usar el dispositivo se desea reiniciar el conteo de los archivos de grabación a un valor inicial, borre todos los archivos de grabación generados hasta el momento y regrese el valor del entrecomillado en el archivo COUNT a cero. Si se omite esta advertencia, los archivos con el mismo número de conteo comenzarán a sobrescribirse.

Control por internet del dispositivo

Para controlar remotamente el dispositivo ingrese al siguiente sitio:

https://io.adafruit.com/AlbertoIztatik/analizador-de-vibraciones

Se desplegara una página como muestra la siguiente imagen, si se desa puede ampliarse el área de control haciendo click en el icono de maximizar dentro de la interfaz:

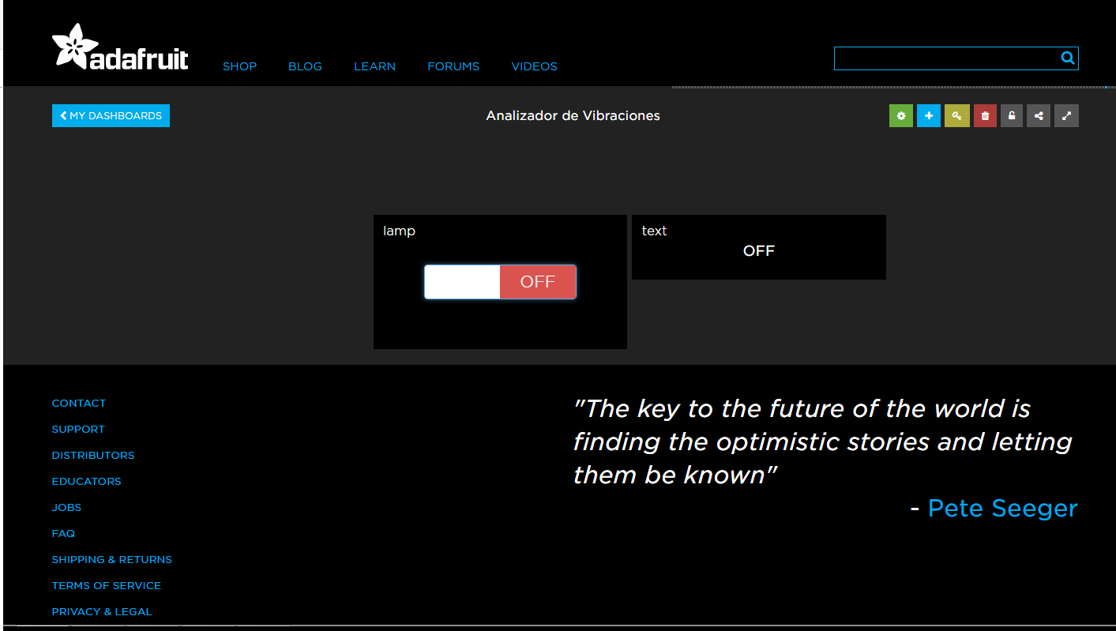
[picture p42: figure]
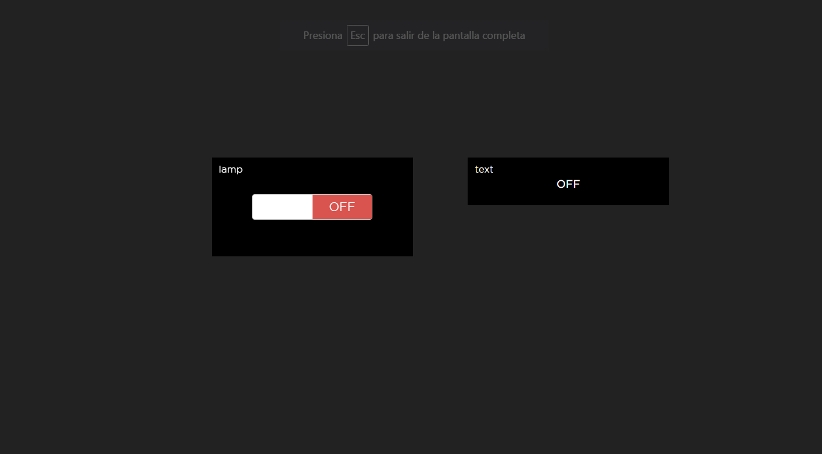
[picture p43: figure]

Figura 5: Interfaz web

Tanto el botón como el cuadro de texto de la interfaz realizan la misma función que el botón de grabación del dispositivo. Si se presiona el botón de la interfaz o se escribe la palabra ON en el cuadro de texto se iniciará una nueva grabación de datos en el dispositivo, volviendo a presionar el botón o escribiendo la palabra OFF y dando enter en el cuadro de texto se detiene la grabación.

La interfaz web proporcionada por la empresa Adafruit es un prototipo que se encuentra aún en fase de desarrollo, por lo que resulta habitual que el dispositivo no reciba la orden de iniciar o detener una grabación al primer intento. Se recomienda hacer un uso mayoritario del cuadro de texto para enviar órdenes y pulsar la tecla enter en repetidas ocasiones, dejando pausas de 1 segundo para asegurar el envío correcto de la orden.

# 3. Reprogramación y cambio de pilas

Para reprogramar el dispositivo siga los siguientes pasos:

1) Retire los tornillos de la tapa superior (transparente) con ayuda de un destornillador
2) Retire la tapa teniendo precaución de notar su alineación original
3) Coloque cables con headers tipo hembra en los headers tipo macho que sobresalen de la tarjeta del dsPic y conéctelos a su programador de preferencia. Tenga especial cuidado de no aplicar demasiada fuerza sobre los circuitos ya que podría romper con facilidad la estructura que los sostiene.
4) Encienda el dispositivo e inicie la reprogramación.
5) Coloque la tapa de la misma manera que esta se encontraba antes de ser retirada y sujétela con los tornillos.

Para cambiar las pilas del dispositivo siga los siguientes pasos:

1) Asegúrese que el led rojo ubicado en la tapa frontal se mantiene encendido sin parpadear al momento de hacer lecturas, esto indica que las pilas necesita una recarga.
2) Retire los tornillos de la tapa inferior con ayuda de un destornillador
3) Retire la tapa teniendo precaución de notar su alineación original
4) Extraiga con precaución el contenedor de pilas y retire las pilas del mismo. De ninguna manera fuerce los componentes ya que esto podría dañarlos. Si encuentra dificultad para extraer las pilas del contenedor, presione con algún elemento puntiagudo las baterías a través de los agujeros que se ubican en la parte trasera del contenedor teniendo cuidado de no dañar las mismas.
5) Coloque las pilas en el cargador e inicie el proceso de carga.
6) Una vez cargadas las pilas, colóquelas en el contenedor e introduzca este último en el dispositivo.

# 7) Coloque la tapa de la misma manera que esta se encontraba antes de ser retirada y sujétela con los tornillos.

Registrador de vibraciones v1.0

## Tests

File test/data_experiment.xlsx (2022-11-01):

Analizador de vibraciones FI-UAEMex
Martes: 16/8/16 23:17:39
EJEX | EJEY | EJEZ
1487 | 1492 | 2117
1509 | 1507 | 2122
1515 | 1507 | 2118
1514 | 1501 | 2123
1511 | 1514 | 2119
1513 | 1509 | 2122
1518 | 1507 | 2131
1511 | 1512 | 2115
1509 | 1508 | 2117
1512 | 1509 | 2123
1514 | 1507 | 2129
1507 | 1512 | 2112
1507 | 1508 | 2119
1511 | 1509 | 2120
1511 | 1501 | 2119
1511 | 1509 | 2118
1509 | 1505 | 2119
1513 | 1509 | 2122
1511 | 1505 | 2113
1514 | 1514 | 2116
1513 | 1507 | 2122
1514 | 1506 | 2132
1511 | 1507 | 2112
1511 | 1511 | 2118
1511 | 1507 | 2122
1513 | 1504 | 2128
1508 | 1513 | 2116
1508 | 1506 | 2122
1510 | 1505 | 2118
1511 | 1507 | 2121
1506 | 1511 | 2119
1511 | 1506 | 2123
1514 | 1505 | 2127
1509 | 1508 | 2112
1507 | 1507 | 2118
1512 | 1508 | 2121
1512 | 1504 | 2132
1510 | 1512 | 2111
1510 | 1508 | 2119
1514 | 1508 | 2121
1514 | 1504 | 2121
1514 | 1514 | 2118
1480 | 1508 | 2128
1514 | 1507 | 2121
1509 | 1505 | 2123
1507 | 1512 | 2119
1512 | 1508 | 2121
1516 | 1506 | 2131
1508 | 1507 | 2110
1507 | 1508 | 2115
1511 | 1509 | 2120
1516 | 1503 | 2132
1509 | 1514 | 2110
1510 | 1506 | 2120
1515 | 1505 | 2121
1513 | 1504 | 2124
1507 | 1514 | 2115
1509 | 1508 | 2121
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

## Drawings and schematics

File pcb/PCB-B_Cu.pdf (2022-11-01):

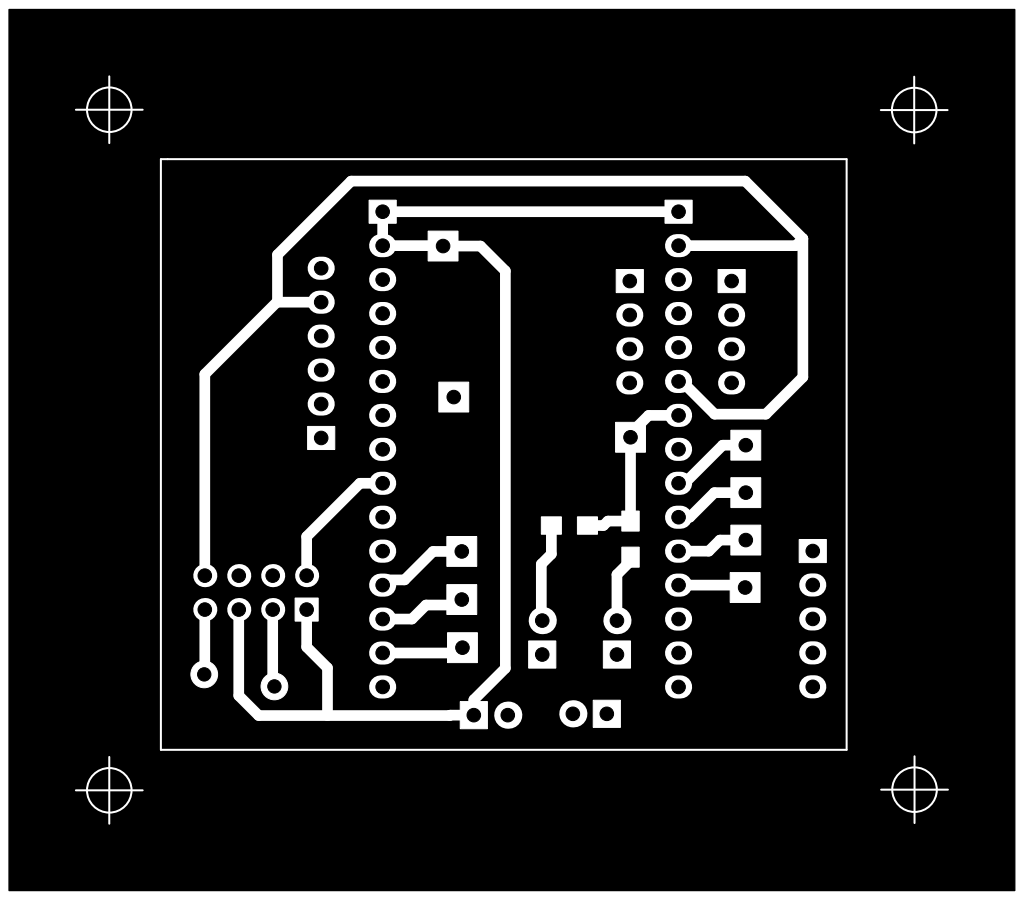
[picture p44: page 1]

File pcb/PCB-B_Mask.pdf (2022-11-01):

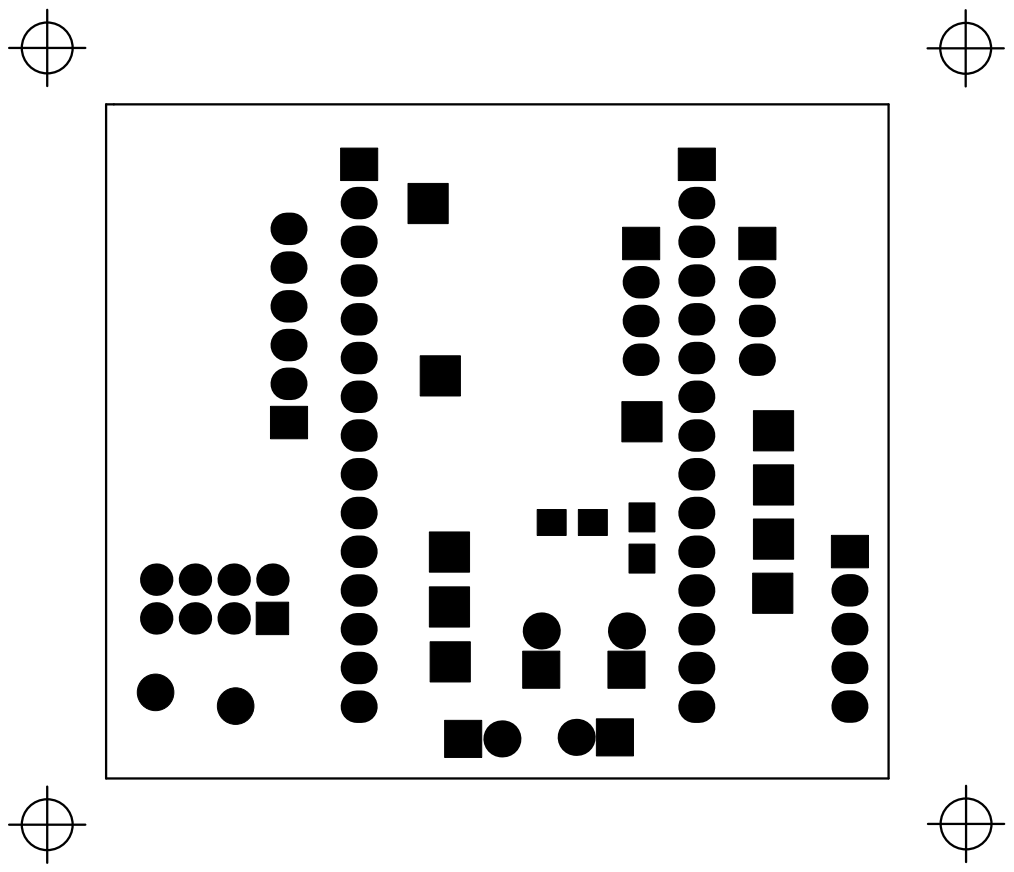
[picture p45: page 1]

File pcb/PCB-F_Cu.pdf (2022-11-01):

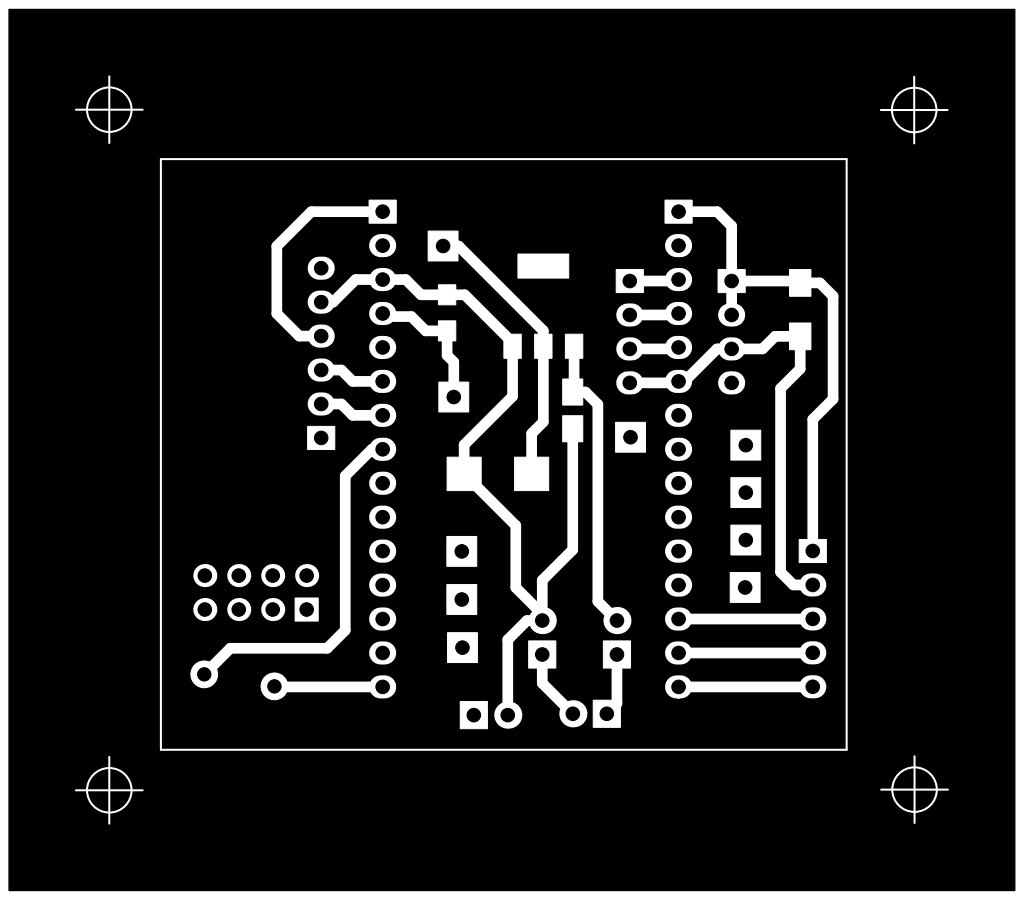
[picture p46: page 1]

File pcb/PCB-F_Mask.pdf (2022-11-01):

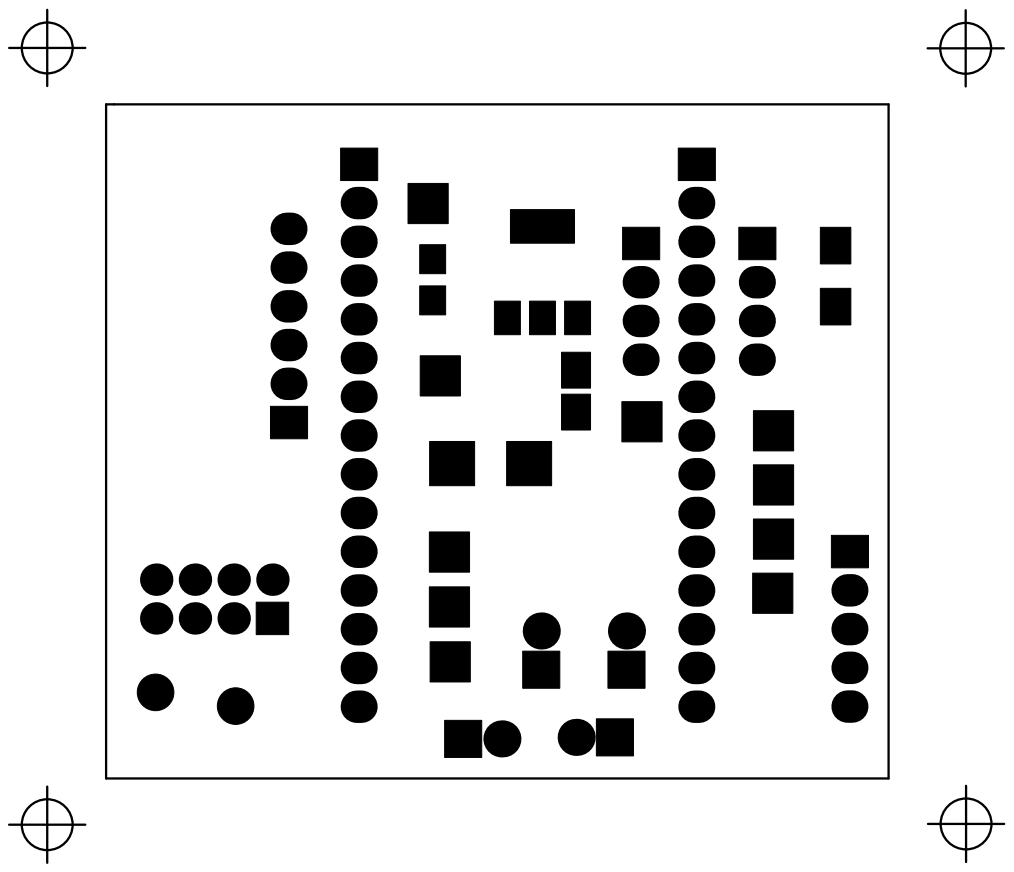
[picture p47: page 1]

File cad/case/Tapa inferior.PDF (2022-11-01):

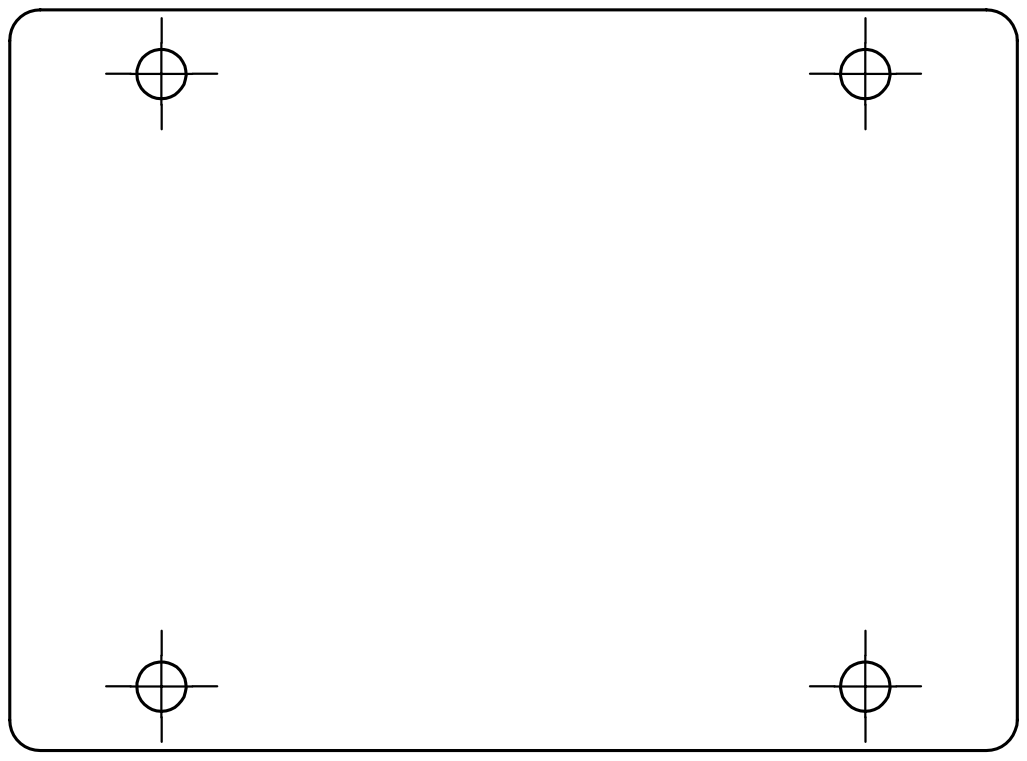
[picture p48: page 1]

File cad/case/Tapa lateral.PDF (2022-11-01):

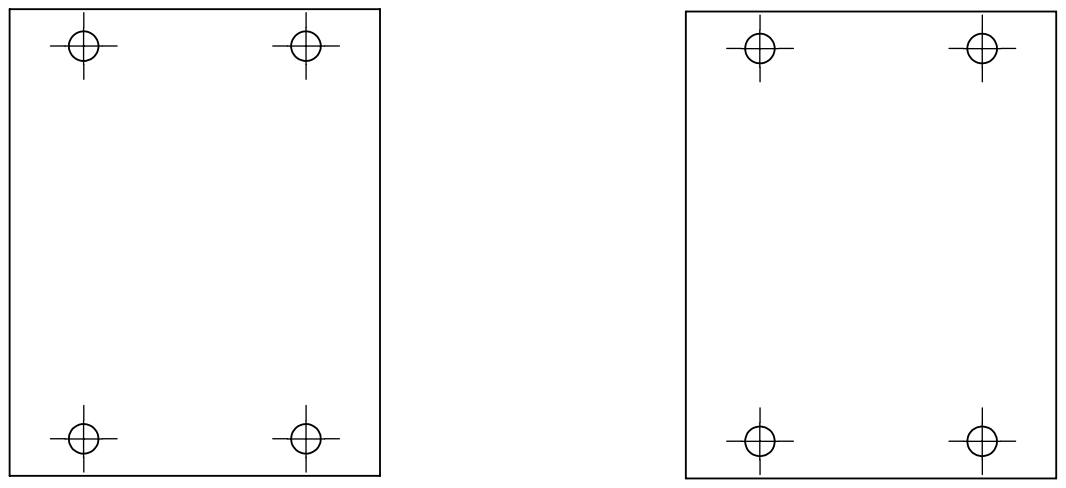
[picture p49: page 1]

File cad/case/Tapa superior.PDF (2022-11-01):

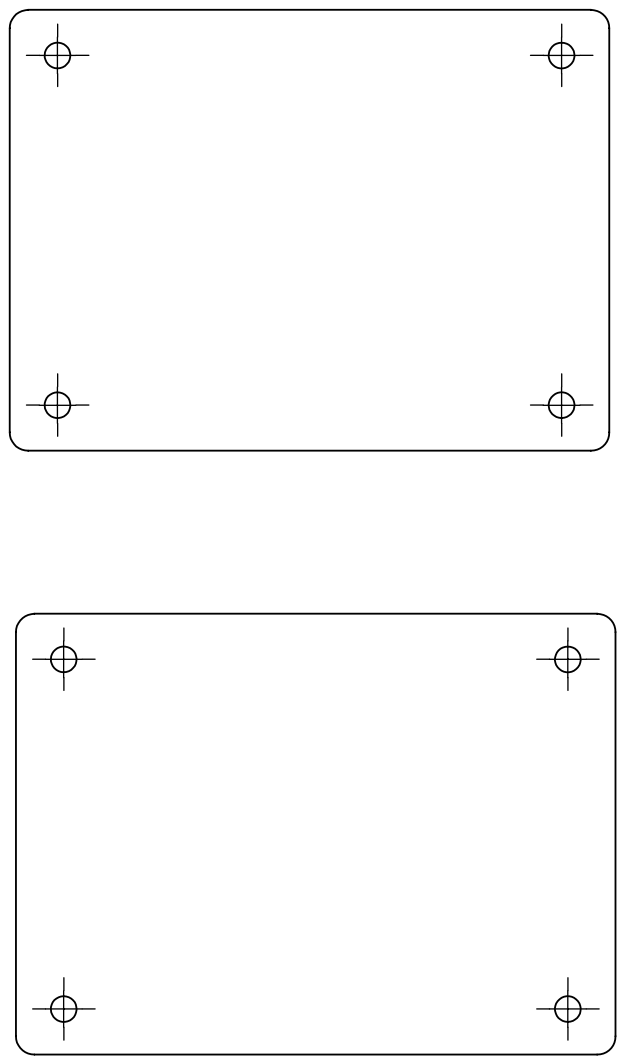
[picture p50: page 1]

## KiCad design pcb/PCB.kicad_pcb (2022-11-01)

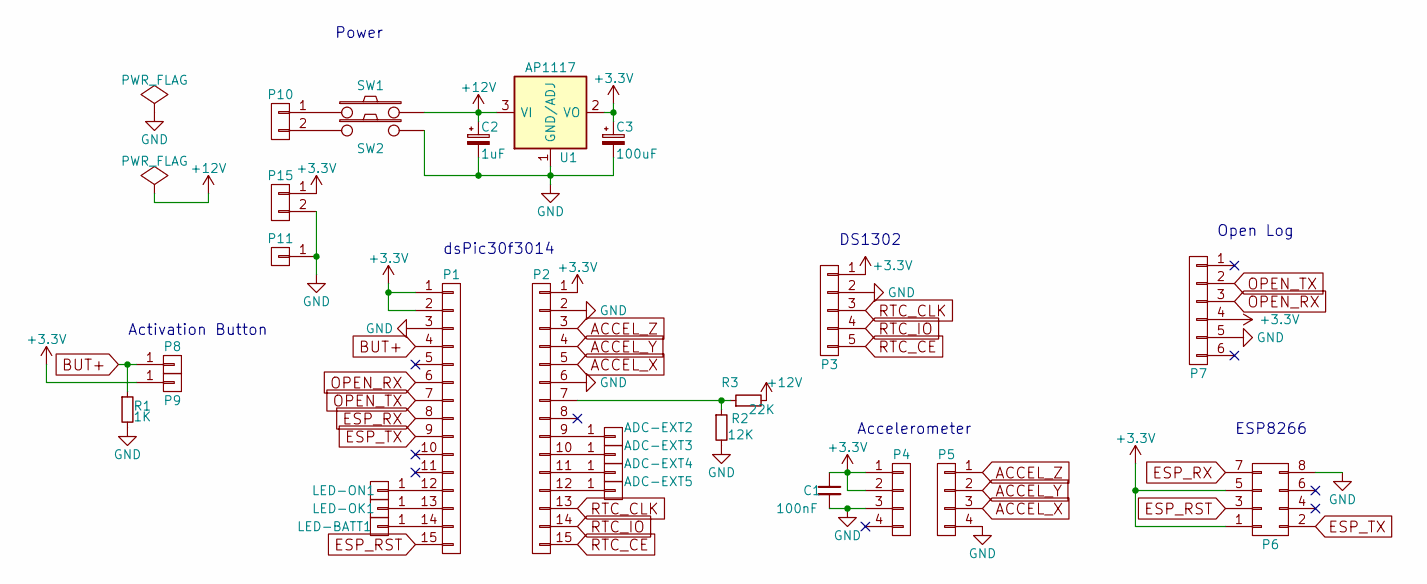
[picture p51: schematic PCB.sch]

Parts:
ADC-EXT2, ADC-EXT3, ADC-EXT4, ADC-EXT5: CONN_01X01; Socket_Strip_Straight_1x01
C1: 100nF; C_1206_HandSoldering
C2: 1uF; c_tant_A
C3: 100uF; c_tant_C
LED-BATT1: CONN_01X01; Socket_Strip_Straight_1x01
LED-OK1: CONN_01X01; Socket_Strip_Straight_1x01
LED-ON1: CONN_01X01; Socket_Strip_Straight_1x01
P1, P2: CONN_01X15; Socket_Strip_Straight_1x15
P3: CONN_01X05; Socket_Strip_Straight_1x05
P4, P5: CONN_01X04; Socket_Strip_Straight_1x04
P6: CONN_02X04; Socket_Strip_Straight_2x04
P7: CONN_01X06; Socket_Strip_Straight_1x06
P8, P9, P11: CONN_01X01; Socket_Strip_Straight_1x01
P10, P15: CONN_01X02; Socket_Strip_Straight_1x02
R1: 1K; R_0805_HandSoldering
R2: 12K; R_0805_HandSoldering
R3: 22K; R_0805_HandSoldering
SW1, SW2: SW_PUSH; Socket_Strip_Straight_1x02
U1: AP1117; sot223

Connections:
+3V3: C1.1, C3.1, P1.1, P1.2, P2.1, P3.1, P4.1, P4.2, P6.1, P6.5, P7.4, P9.1, P15.1, U1.2 (VO)
+12V: C2.1, R3.2, SW1.2, U1.3 (VI)
ACCEL_X: P2.5, P5.3
ACCEL_Y: P2.4, P5.2
ACCEL_Z: P2.3, P5.1
BUT+: P1.4, P8.1, R1.1
ESP_RST: P1.15, P6.3
ESP_RX: P1.8, P6.7
ESP_TX: P1.9, P6.2
GND: C1.2, C2.2, C3.2, P1.3, P2.2, P2.6, P3.2, P4.3, P5.4, P6.8, P7.5, P11.1, P15.2, R1.2, R2.2, SW2.2, U1.1 (GND/ADJ)
unnamed: ADC-EXT2.1, P2.9
unnamed: ADC-EXT3.1, P2.10
unnamed: ADC-EXT4.1, P2.11
unnamed: ADC-EXT5.1, P2.12
unnamed: LED-BATT1.1, P1.14
unnamed: LED-OK1.1, P1.13
unnamed: LED-ON1.1, P1.12
unnamed: P2.7, R2.1, R3.1
unnamed: P10.1, SW1.1
unnamed: P10.2, SW2.1
OPEN_RX: P1.6, P7.3
OPEN_TX: P1.7, P7.2
RTC_CE: P2.15, P3.5
RTC_CLK: P2.13, P3.3
RTC_IO: P2.14, P3.4

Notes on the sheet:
dsPic30f3014
DS1302
Open Log
Accelerometer
ESP8266
Power
Activation Button

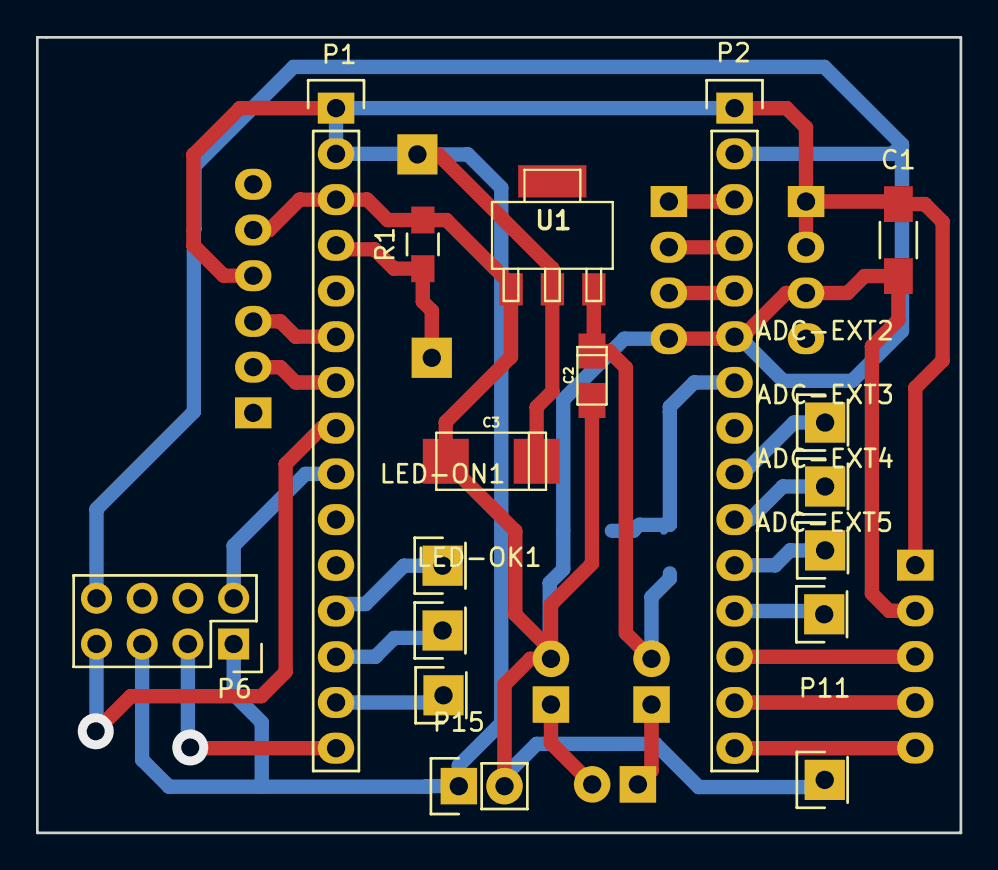
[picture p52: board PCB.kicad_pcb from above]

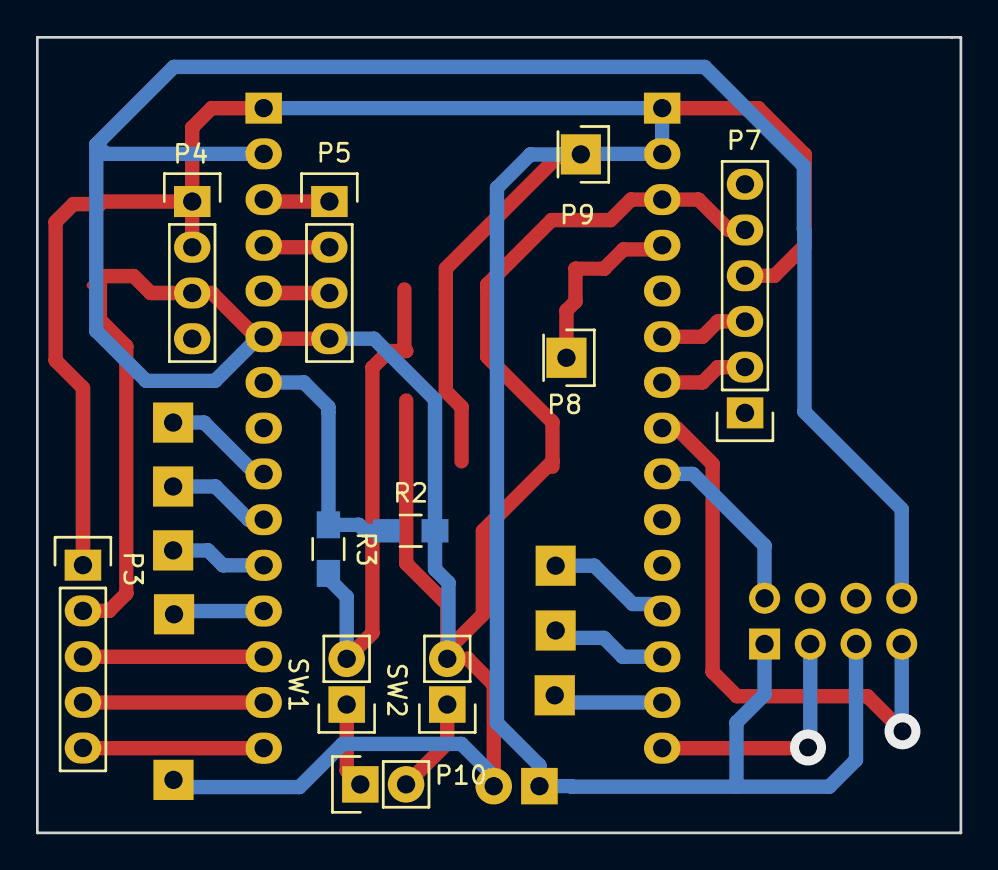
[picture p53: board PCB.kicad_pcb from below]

Board: 2 copper layers, 51.3 x 44.2 mm, 28 parts (11 on the bottom side), 25 nets.

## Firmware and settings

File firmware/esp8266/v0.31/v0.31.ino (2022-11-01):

/***************************************************
  Adafruit MQTT Library ESP8266 Example

  Must use ESP8266 Arduino from:
    https://github.com/esp8266/Arduino

  Works great with Adafruit's Huzzah ESP board:
  ----> https://www.adafruit.com/product/2471
  Adafruit invests time and resources providing this open source code,
  please support Adafruit and open-source hardware by purchasing
  products from Adafruit!

  Written by Tony DiCola for Adafruit Industries.
  Adafruit IO example additions by Todd Treece.
  MIT license, all text above must be included in any redistribution
 ****************************************************/
#include <ESP8266WiFi.h>
#include "Adafruit_MQTT.h"
#include "Adafruit_MQTT_Client.h"

// function prototypes
void connect(void);
void recieve_string(char *punt);


char WLAN_SSID[20], WLAN_PASS[20],ck=0;
/****************************** Pins ******************************************/

#define LAMP            2  // power switch tail

//************************* Adafruit.io Setup *********************************/

#define AIO_SERVER      "io.adafruit.com"
#define AIO_SERVERPORT  1883
#define AIO_USERNAME    "AlbertoIztatik"
#define AIO_KEY         "003859a64a634978847115cff8c2b450"

/************ Global State (you don't need to change this!) ******************/

// Create an ESP8266 WiFiClient class to connect to the MQTT server.
WiFiClient client;

// Store the MQTT server, client ID, username, and password in flash memory.
// This is required for using the Adafruit MQTT library.
const char MQTT_SERVER[] PROGMEM    = AIO_SERVER;
// Set a unique MQTT client ID using the AIO key + the date and time the sketch
// was compiled (so this should be unique across multiple devices for a user,
// alternatively you can manually set this to a GUID or other random value).
const char MQTT_CLIENTID[] PROGMEM  = __TIME__ AIO_USERNAME;
const char MQTT_USERNAME[] PROGMEM  = AIO_USERNAME;
const char MQTT_PASSWORD[] PROGMEM  = AIO_KEY;

// Setup the MQTT client class by passing in the WiFi client and MQTT server and login details.
Adafruit_MQTT_Client mqtt(&client, MQTT_SERVER, AIO_SERVERPORT, MQTT_CLIENTID, MQTT_USERNAME, MQTT_PASSWORD);

/****************************** Feeds ***************************************/

// Setup a feed called 'lamp' for subscribing to changes.
// Notice MQTT paths for AIO follow the form: <username>/feeds/<feedname>
const char LAMP_FEED[] PROGMEM = AIO_USERNAME "/feeds/lamp";
Adafruit_MQTT_Subscribe lamp = Adafruit_MQTT_Subscribe(&mqtt, LAMP_FEED);

/*************************** Sketch Code ************************************/

void setup() {

  // set power switch tail pin as an output
  pinMode(LAMP, OUTPUT);
  digitalWrite(LAMP, 0);
  
  Serial.begin(57600);
   delay(10);
   recieve_string(WLAN_SSID);
   recieve_string(WLAN_PASS);
   Serial.println(WLAN_SSID);
   Serial.println(WLAN_PASS);

  WiFi.begin(WLAN_SSID,WLAN_PASS);
  while (WiFi.status() != WL_CONNECTED) {
    delay(500);
    Serial.print(F("."));
  }
  Serial.print(F("+"));
  // listen for events on the lamp feed
  mqtt.subscribe(&lamp);

  // connect to adafruit io
  connect();

}

void loop() {

  Adafruit_MQTT_Subscribe *subscription;

  // ping adafruit io a few times to make sure we remain connected
  if(! mqtt.ping(3)) {
    // reconnect to adafruit io
    if(! mqtt.connected())
      connect();
  }

  // this is our 'wait for incoming subscription packets' busy subloop
  while (subscription = mqtt.readSubscription(1000)) {

    // we only care about the lamp events
    if (subscription == &lamp) {

      // convert mqtt ascii payload to int
      char *value = (char *)lamp.lastread;
      
     // Apply message to lamp
      String message = String(value);
      message.trim();
      if (message == "ON") {digitalWrite(LAMP, HIGH);Serial.print("s");}
      if (message == "OFF") {digitalWrite(LAMP, LOW);Serial.print("e");}


    }

  }

}

// connect to adafruit io via MQTT
void connect() {

  Serial.print(F("..."));

  int8_t ret;

  while ((ret = mqtt.connect()) != 0) {

    switch (ret) {
      case 1: Serial.println(F("-")); break;
      case 2: Serial.println(F("-")); break;
      case 3: Serial.println(F("-l")); break;
      case 4: Serial.println(F("-")); break;
      case 5: Serial.println(F("-")); break;
      case 6: Serial.println(F("-")); break;
      default: Serial.println(F("-")); break;
    }

    if(ret >= 0)
      mqtt.disconnect();

    Serial.println(F("..."));
    delay(5000);

  }

  Serial.println(F("+"));

}

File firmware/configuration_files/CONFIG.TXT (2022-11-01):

57600,26,3,2,0,0,0
baud,escape,esc#,mode,verb,echo,ignoreRX

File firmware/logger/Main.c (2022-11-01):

/*
 * File:   Main.c
 * Author: Carlos Alberto Sánchez Delgado
 *
 * Created on 12 de julio de 2016, 11:01 AM
 */

#include "Configuration.h"


#define button PORTFbits.RF0
#define LED_batt   LATCbits.LATC13 
#define LED_active LATCbits.LATC14 
#define LED_on     LATDbits.LATD8 
char rec[20], function_flag=0,file_flag=0;

int main(void) { 
    unsigned int accel_dataX,accel_dataY,accel_dataZ,batt_stat ;  
    unsigned int counter=0;
    SYSTEM_initialize();

    LED_on = 1;
    LED_batt = 1;
    
    while (1){ 
        if(button&&!function_flag){function_flag =1;file_flag=1;__delay_ms(300);while(button);__delay_ms(200);}      
        if(file_flag==1){file_flag=0;OPENLOG_newfile();}

        while (TMR1_FLAG && function_flag){    
            
            LED_active =1;
            accel_dataX = ACCEL_get(x);
            accel_dataY = ACCEL_get(y);
            accel_dataZ = ACCEL_get(z);
            batt_stat = BATT_get();
            OPENLOG_completewrite(counter++,accel_dataX,accel_dataY,accel_dataZ);  
            if (batt_stat<=2100) LED_batt=1;                     // aprox 6.10v de las pilas 
            else LED_batt=0;
            TMR1_FLAG=0;
        }
        if(button&&function_flag){function_flag =0;file_flag=2;__delay_ms(300);while(button);__delay_ms(200);}
        if(file_flag==2) {OPENLOG_printtime();file_flag=0;LED_active =0;counter=0;}
    }
    return 0;
}
